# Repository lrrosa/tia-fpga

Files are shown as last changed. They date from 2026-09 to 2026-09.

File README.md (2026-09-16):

# tia-fpga

An FPGA replacement for the **Television Interface Adaptor (TIA)** — the custom
`C010444` / `C010444D` (NTSC) video and sound chip of the Atari 2600.

Revision **B** is the digital interface board between a Sipeed Tang Nano 9K
module and the TIA's DIP-40 socket, for use with a real 6507 (on a breadboard or
in an actual 2600). Revision A, the first study, was never built.

| Front | Back |
|:---:|:---:|
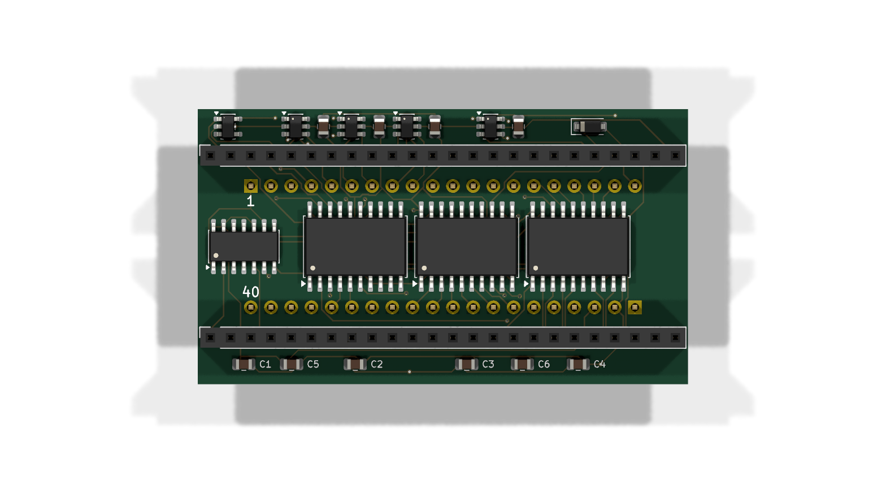
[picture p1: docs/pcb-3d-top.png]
Front of the board
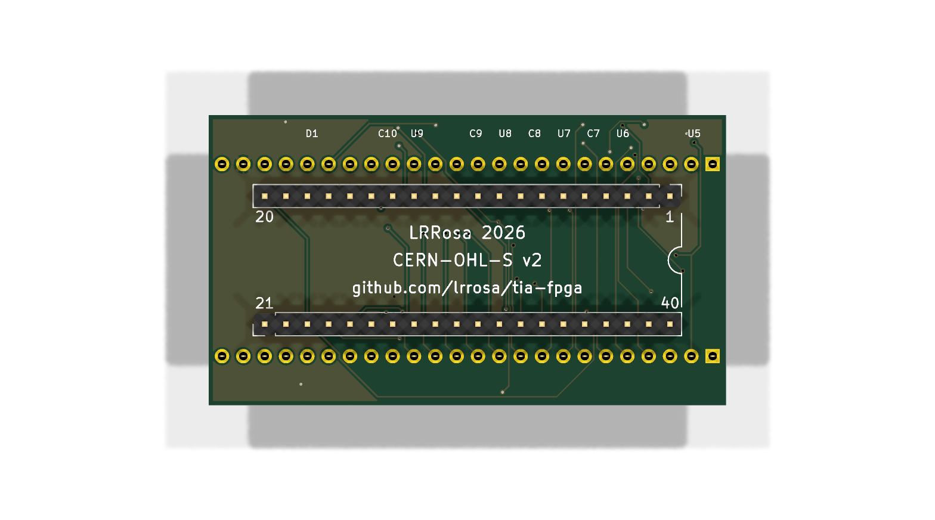
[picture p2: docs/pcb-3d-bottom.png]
Back of the board
|  |  |
| Tang Nano sockets face **up**; the logic sits in the channel between the rows | The TIA's DIP-40 pins face **down** into the socket, over the ground pour |

61.6 × 34.54 mm, two layers. Every row lands on the 2.54 mm grid — the
DIP-40's 15.24 mm and the Tang Nano's 22.86 mm — and the board is a little
shorter than the module it carries, as it has to be: in a real 2600 the TIA,
the 6507 and the RIOT sit millimetres apart.

---

## Why this exists

The TIA has **6,193 transistors** — 1,657 of which are NMOS pull-ups, leaving
about 4,500 of actual logic. It fits in any modern FPGA with room to spare:
synthesising a known implementation yields **311 flip-flops** and roughly 2,200
basic gates.

Size was never the problem. Two other things are:

1. **The analogue boundary.** The chroma generator is an analogue delay line
   trimmed by an external 500 kΩ potentiometer (pin 10, `DEL`). It has no direct
   digital equivalent.
2. **5 volts.** No FPGA with enough capacity is 5 V tolerant. And the TIA
   generates the 6507's Φ0 clock, which requires
   V<sub>IH</sub> = V<sub>cc</sub> − 0.2 V ≈ **4.8 V** — not a TTL level. A 3.3 V
   output will not clock the 6507 reliably, and the failure mode is nasty: it
   works intermittently, or works cold and quits once warm.

This revision solves (2) and leaves (1) for later.

## What is on the board

| Ref | Part | Function |
|-----|---|---|
| J1, J4 | 1x24 sockets | Sipeed Tang Nano 9K module (GW1NR-LV9QN88PC6/I5): J1 takes its **J6** row, J4 its **J5** |
| J2, J3 | 1x20 SIP strips | Plug into the DIP-40 socket in place of the C010444 |
| D1 | MBR0540 | Feeds the module's 5 V pin from the socket, and blocks its USB from feeding the console |
| **U1** | **74AHCT125** | **Φ0 and RDY buffer, powered from +5 V.** The critical part |
| U2 | 74LVC245A | D0–D7 bidirectional bus. A side = FPGA, B side = TIA |
| U3 | 74LVC541A | A0–A5 and R/W into the FPGA; Φ2 buffered to a spare pad |
| U4 | 74LVC541A | /CS0, /CS3, triggers I4/I5 and the 3.579545 MHz crystal clock |
| U5 | 74LVC1G32 | `/CS0 OR /CS3`: `/OE` for the 245, and the FPGA's chip select |
| U6–U9 | 74LVC2G07 | Open-drain drivers for SYNC, LUM0–2, COL, BLK, AUD0 and AUD1 |

The video and sound pads — SYNC, LUM0–2, COL, BLK, AUD0 and AUD1 — each go
through one channel of U6–U9. On the die every one of them is a pull-down
transistor and nothing more; the buffers make the board's pins the same, open
drain and 5 V tolerant, so the console's own pull-ups set every level. See
*Pads and levels* below.

Pin 10 (`DEL`) is marked no-connect: it is the colour trim pot, which has no
function in a replacement.

Neither of the 245's control lines comes from the FPGA. The A side faces the
FPGA, so `DIR` can be driven straight from the buffered R/W (`DIR`=1, a read,
sends FPGA → TIA), and `/OE` comes from U5. That is deliberate — see the pin
budget below.

## The pin budget, and why it constrains everything

The Tang Nano 9K's headers are 2×24, but **only 29 of those 48 pins are usable
3.3 V GPIO**:

| | Count | |
|---|---|---|
| J5 pins 1–22 | 22 | banks 1/2 at 3.3 V — all usable |
| J6 pins 1, 10, 11, 19–22 | 7 | 3.3 V — usable |
| J6 pins 2–9 | 8 | **BANK3 at 1.8 V — not usable at 3.3 V** |
| J5 23–24, J6 12–17 | 8 | HDMI differential pairs — not GPIO |
| J6 18, 23, 24 | 3 | +5V (fed through D1), GND, +3V3 |

Verified against both revisions of the official Sipeed board schematic (3672 and
3674), which agree exactly. Many of the 29 are shared with onboard peripherals
(SD card, RGB LCD, SPI LCD); they are free to reuse as long as you do not fit
those.

**Rev B uses all 29 with nothing spare.** A fully featured TIA needs about 36.
`BLK` has its pin because the FPGA reads `/CS0 OR /CS3` from U5, which makes it
for the 245 anyway, instead of taking the two selects separately.

**Chroma is fitted.** `F_COL` took the pin that used to carry Φ2, and that trade
is deliberate rather than grudging: the FPGA generates Φ0 itself, so it knows
where it is in the bus cycle and can time accesses off its own clock instead of
the 6507's output. It costs a little timing fidelity and buys back colour on the
composite and RF path — which is the difference between a board that only works
with an HDMI monitor and one that revives a console with a dead TIA while
keeping its original video. Φ2 is still buffered by U3, brought out to an
unconnected pad for a future revision.

What still does not fit: the four paddle inputs plus their dump/compare control.

Two ways to get the remaining pins back:

1. **Recover J6/2–9** (8 pins) with a local 1.8 V LDO and a fourth buffer powered
   at 1.8 V. LVC parts run down to 1.65 V and their inputs stay 5 V tolerant, so
   this works — it just adds a rail. This is the cheapest way to the paddles.
2. **Drop the module and put a bare FPGA on the board.** A part in a TQFP-100
   gives ~78 I/O against the module's 29, which ends the pin shortage outright,
   removes U5, brings Φ2 back and makes the paddles possible — and collapses a
   ~20 mm tall stack into a 1 mm chip, which matters if this has to live inside
   a closed console. It costs fine-pitch soldering and your own configuration
   and power plumbing. See `docs/bare-fpga.md`.

This is the single most important thing to know before ordering parts: the Tang
Nano 9K is big enough in *logic* by a wide margin, and tight in *pins*. Every
compromise in this design traces back to that.

## The board

Rev B is a 2-layer, **61.6 × 34.54 mm** board — shorter than the Tang Nano it
carries. In a real 2600 the TIA, the 6507 and the RIOT sit millimetres apart,
ringed by resistor networks and the cartridge slot, so the board cannot spread
sideways. The two sets of rows face opposite ways:

| y (mm) | Row | Side | Faces |
|---|---|---|---|
| 5.84 | J1 — Tang Nano **J6** | F.Cu | socket, **up** |
| 9.65 | J2 — TIA pins 1–20 | **B.Cu** | pins, **down** into the socket |
| 24.89 | J3 — TIA pins 21–40 | **B.Cu** | pins, **down** |
| 28.70 | J4 — Tang Nano **J5** | F.Cu | socket, **up** |

Both pitches land on the 2.54 mm grid: the DIP-40 rows 15.24 mm apart, the Tang
Nano's 22.86 mm, and the DIP pair centred between the sockets — 3.81 mm of gap
on each side. Which socket takes which module row is not free — see
[Which row is which](#which-row-is-which). SMD logic sits on the front in the
15.24 mm channel between the DIP rows. The open-drain drivers and their
capacitors sit in the top margin, right above the TIA pins they drive, with D1
beside them, and the channel's decoupling in the bottom margin.

| | |
|---|---|
| Size | 61.6 × 34.54 mm, 2 layers |
| Components | 24 — SOIC/SOT-23 logic, 0805 capacitors, one diode, through-hole connectors |
| Routing | 534 segments, 39 vias, 1.48 m of copper |
| Ground | B.Cu pour, 759 mm² in two islands, tied together by track |
| Track / clearance | 0.18 mm / 0.13 mm |
| **DRC** | **0 violations, 0 unconnected pads** |

### Pin assignment is solved, not listed

Which signal sits on which header position is free — any GPIO can carry any
signal — so it is chosen to put each FPGA pin as close as it can be to the pad
its net really reaches: the buffer or gate between it and the TIA socket, not
the socket pin beyond it. Solved as an assignment problem (Hungarian, over the
29 usable positions, Manhattan distance to those pads), the whole set comes to
571 mm. `F_OSC` is held to J6/1, the right PLL's own input, which costs 25.6 mm
of that and keeps the colour clock off the FPGA's general routing.

The sum is what the module's own geometry allows: J5 carries 22 of the 29
signals and sits on the row *away* from the TIA's pins 1–20, so most of the bus
crosses the channel whatever the assignment does. Solving it still beats the
alternative — the same signals laid out by hand come to 685 mm.

Rev A measured the distance to the TIA pin itself, which left out the detour
through the buffers: its data and chip-select lines crossed the board twice.
The buffers stay ordered left to right by the centroid of what they carry,
**U1, U4, U3, U2**, and against rev A the board saves copper while gaining five
parts:

| | rev A | rev B |
|---|---|---|
| Segments | 601 | **534** |
| Vias | 31 | **39** |
| Copper | 1.68 m | **1.48 m** |

`fpga/tia_fpga.cst` carries the result. Do not reshuffle those `IO_LOC` lines
casually — the layout depends on them.

Autorouted with [Freerouting](https://github.com/freerouting/freerouting) 2.2.4:
all 120 nets in about 12 s but three ground connections. Two are closed with a
via dropped on the branch's own track where it passes over the pour, and the
last two capacitors are tied to their neighbours along the free lane that runs
just inside the top edge. The channel leaves only ~1.1 mm between the header pads and the SOIC
pads, so the geometry decides whether it routes at all: it takes 0.13 mm
clearance and 0.18 mm track. The ground pour is added **after** routing —
Freerouting reads a pour as an obstacle and goes effectively single-layer if one
is present.

Files: `tia-fpga.kicad_pcb`, renders in `docs/`, fabrication output in `gerbers/`.

### Ordering a board

The files in `gerbers/` are ready for any PCB house as they are — Gerber X2
plus Excellon drill, with `FABRICATION-NOTES.txt` alongside them; zip them with
the files at the root of the archive. Nothing in it needs more than standard
low-cost capability:

| | |
|---|---|
| Size / layers | 61.6 × 34.54 mm, 2 layers, 1.6 mm FR4 |
| Min track / clearance | 0.18 mm / 0.13 mm |
| Drills | 0.30 mm (vias), 1.00 mm (connectors) |

`docs/bom-production.csv` is the parts list with suggested orderable numbers.
Three assembly points that are easy to get wrong:

- **J2/J3 mount on the BACK, pins facing DOWN**, and want **round machined
  pins** — square header pins damage a DIP socket.
- **U5–U9, C7–C10 and D1 carry their designators on the back silkscreen**,
  right behind each part: the top margin has no room for them on the front.
- **The module goes in component side up, USB-C end to the left** — see below.
- **The back silkscreen carries the licence notice** — `CERN-OHL-S v2`,
  `LRRosa 2026` and `github.com/lrrosa/tia-fpga`, between the two rows of TIA
  pins. The licence asks for it to travel with the board; keep it on a respin.
- **Pin 1 of the TIA is at the half-moon end.** The back carries that half moon,
  keyed like the chip's own package, and the numbers 1, 20, 21 and 40 beside the
  corner pads; the front repeats 1 and 40.

### Which row is which

The Tang Nano's two rows are **22.86 mm** apart (9 × 2.54), from Sipeed's own
dimension drawing, `Tang_Nano_9K_3672_size`. Pin 1 of both rows is at the USB-C
end, 2.55 mm from that edge; the HDMI connector is at the other end and
overhangs this board by about 7.5 mm, with a millimetre of module sticking out
at the USB end as well. Both hang in free air, 20 mm above the console.

Looking down at the module with the USB-C end on the left, **J6 is the upper
row and J5 the lower one**, so J1 takes J6 and J4 takes J5. Three things say so
and agree: the pin numbers silkscreened on the module's underside, the QN88's
own pin order on the top-side photo in Sipeed's datasheet, and third-party
carrier boards for the module. On your own board, look for **63** beside pin 1
of one row and **38** beside pin 1 of the other: 63 is J6/1, which this board
wires to `F_OSC`.

Rev A and the first cut of rev B had both of these wrong — 20.32 mm, and the
rows the other way round. Nothing was ever fabricated from them.

The DIP-40 row spacing (15.24 mm) is fixed by the package and is not a guess.

**The board needs tall pins.** It overhangs the neighbouring 6507 and RIOT, which
sit proud of the 2600's PCB in their own sockets. Standard DIP header pins would
put this board straight into them; a socket extender or long machined pins are
required. Measure the vertical clearance in your console — the Tang Nano's HDMI
connector adds roughly 5 mm on top.

**There are no mounting holes.** The board is held by its own pins in the TIA
socket, and there is nothing to screw into inside a 2600. Adding holes only
forced the board larger, so they were dropped.

### Known limitations

- The four paddle inputs still do not fit — see the pin budget above.
- No ground pour on F.Cu; only B.Cu is poured.

### Pads and levels

Reading the die's netlist for the RTL settled something the schematic had
assumed. **Every video and sound pad on the TIA — SYNC, LUM0–2, COL, AUD0,
AUD1, and BLK and RDY too — is a pull-down transistor and nothing else.** None
of them can drive high. Φ0 is the only output with a real driver on both
sides.

The console schematics show the other half:

| | 2600A, rev 16 | 2600 (the original board) |
|---|---|---|
| LUM0–2, SYNC | R218–R221, 3.3–4.7 kΩ to +5 V, straight into the summing resistors (R214–R217: 27, 47, 110, 24 kΩ) | R218–R221, 3.3 kΩ to +5 V, into a CD4050 run from a divider off +5 V (R231, R232: about 3.6 V), then the summing resistors (R222–R224, R234: 12, 24, 47, 10 kΩ) |
| COL | R228, 1 kΩ to +5 V; C210, 47 pF, to a second 1 kΩ pull-up (R211); 6.8 kΩ and 22 pF into the sum | R212, 1 kΩ to +5 V; C212, 47 pF, to a second 1 kΩ pull-up (R214); 22 pF and 6.8 kΩ into the sum |
| BLK | R234, 820 Ω, into the COL node (revs 14 and 15: not connected) | R213, 680 Ω, into the COL node |
| AUD0, AUD1 | joined; R206, 1 kΩ to +5 V; 0.1 µF and 18 kΩ into the sound oscillator | joined; R208, 1 kΩ to +5 V; the same coupling |

PAL consoles use a different TIA (C011903): one sound pad, AUD on pin 13 with
its own 1 kΩ pull-up, while pins 12 and 8 carry the PAL signals. This board is
for the NTSC chip.

Rev B follows the die:

- **Open drain, 5 V tolerant.** Each of those pads goes through one channel of
  a 74LVC2G07 (U6–U9) powered at 3.3 V. The FPGA drives the channel's input:
  0 pulls the socket pin low, 1 lets it go, and the console's pull-up takes the
  line wherever it took the TIA's — 5 V on a 2600A's luma lines, the CD4050's
  input on an original 2600, the colour and sound nodes through their 1 kΩ.
  Nothing on the socket side reaches the FPGA's pins.
- **BLK is driven.** It pulls low through the whole blanking interval. On the
  original 2600 (through 680 Ω) and the 2600A from rev 16 (820 Ω) it drags the
  colour node down with it: against the 1 kΩ pull-up that node only reaches
  about 2 V while blanking, so the burst — the only colour sent then — gets
  well under half the swing of the picture's colour, and a TV sets its colour
  gain by the burst. On revs 14 and 15 of the 2600A the pin is not connected,
  and nothing changes.
- **The two sound pins are joined** by a trace on an unmodified 2600, which
  open drain makes harmless either way. By default `tia_board.v` still puts
  the same pulse-width mix of both channels on both pins; for a console
  modified for stereo, `AUDIO_STEREO = 1` gives each pin its own channel, in
  non-overlapping halves of the pulse frame so the two still add correctly
  wherever they meet.
- **No video network on the board.** Rev A carried a copy of the console's
  resistor network, for use outside a console. With open-drain pads it would
  have needed all of it — pull-ups, summing resistors, the colour coupling and
  BLK's resistor — so rev B leaves it off. To take video from the socket pins
  on a breadboard, build the 2600A rev 16 column of the table above.

## Two ways to use this

**Reviving a dead console.** Pull the failed TIA, drop this in its socket, and
keep the 2600's own RF modulator or composite mod. Chroma, luma, sync and audio
come out on the same socket pins the original chip used, open drain as the
chip's are, so the console's video path is untouched.

**As a development target.** Plug it into a breadboard next to a real 6507.
The Tang Nano's HDMI connector would cost no header pins — its pins are
dedicated differential pairs on the module — but the RTL has no TMDS encoder
yet, so for now the picture comes from the socket pins, through a network like
the console's.

## The RTL

`rtl/` holds the core: horizontal counter, playfield, two players, two
missiles, ball, collisions, HMOVE, audio and the bus interface, in eleven files
of plain Verilog-2005, plus `tia_board.v`, which puts it on this board. `sim/`
holds the test harness the section below argues for, and it is not
aspirational: the core is checked against
[Sim2600](https://github.com/gregjames/Sim2600) half clock by half clock, on a
real game and on test cartridges written to hit each feature from every phase
that matters.

```bash
python sim/run.py
```

Against Donkey Kong from power-on to its first picture, and against every test
cartridge -- playfield, players, missiles, ball, collisions, HMOVE with Cosmic
Ark, resets at every phase of HBLANK, vertical delay and both sound cartridges
-- the core matches the die on every pin at every half clock.
[`sim/README.md`](sim/README.md) has the table. (The Donkey Kong traces are regenerated locally rather
than committed, since they carry the game's artwork.)

**Sim2600 wires one clock wrong, and both wirings are now in the suite.**
Upstream Sim2600 feeds the TIA's Φ2 input from the 6507's Φ1 output, the
inverse of what the console does. The die only looks at that pin through
write strobes, so everything still worked, but every write landed on the other
half of the colour clock from where a real console puts it. With the console's
wiring (`sim/patches/sim2600-phi2.patch`, traces in `sim/traces/phi2/`), five
of the core's timing rules turned out to have been fitted to the wrong side
and were re-read from the netlist — RSYNC's restart, RDY's release, how
long a reset holds an object's clock, the size gate of stretched players and
when HMOVE's comparators see a new value. The last mismatch was a mechanism
no rule had covered: HMOVE pulses in the visible line merge into the object
clocks and show on the pads half a colour clock early. The core now matches
both sets on every pin of every trace.

**The board.** `rtl/tia_board.v` is everything between the core and the board's
pins: the core's clock from a PLL locked to the console's crystal, Φ2 rebuilt
from the Φ0 the board makes itself, the data bus, chroma as that clock shifted
in phase by hue, and sound as pulse width. `fpga/tia_fpga_top.v` adds the Gowin
PLL, bus buffers and chroma ODDR. `sim/tb_board.v` replays the console-wired
traces into the board logic and checks every pin it drives, and
`fpga/build_gowin.tcl` builds the bitstream with Gowin EDA — from a directory
whose path has no spaces, since Gowin's place and route will not run in one
that does.

Getting there turned up a good deal the published documentation does not say,
all of it now in the source: which edge of the colour clock each latch runs on;
that Φ0 is a 50 per cent square wave reloaded by the horizontal counter; what
RSYNC actually does, which Towers left as "requires more investigation"; that
HMOVE's first compare must come before its first decrement, or an HMxx of -8
moves an object sixteen pixels the wrong way; that HMOVE's pulses past HBLANK
merge into the object clocks instead of counting; and exactly when a mid-line playfield
write reaches the screen. Once the harness could record the die's internal
wires as well as its pins, the netlist itself settled the rest: how a RESxx
strobe really resets an object -- by holding its clock, not by zeroing its
counter -- and how the sound counters are clocked, down to the discovery that
the two audio channels are not wired alike.

**Clocking.** The real chip is clocked by the 3.58 MHz colour clock and uses
both its edges. This core takes a faster system clock and treats the colour
clock as a signal to oversample, so everything is one clock domain, one edge,
no gated clocks. On this board `clk0` comes from the console's own crystal
through U4 and the system clock from a PLL, so the core stays locked to the
machine it is plugged into.

## Status

- [x] Rev B schematic — passes KiCad 10 ERC with 0 violations
- [x] FPGA pin assignment (`fpga/tia_fpga.cst`)
- [x] PCB layout — rev B routed, ground pour, DRC clean (0 violations, 0
      unconnected pads)
- [x] Open-drain video and sound pads and `BLK` on pin 6 — U6–U9, with
      `sim/tb_board.v` checking `BLK` against the die
- [x] Sim2600 test harness — traces, replay testbench, test cartridges
- [x] TIA RTL — matches the die on a real game and on every test cartridge
- [x] Audio -- read off the die's netlist; both channels match on every trace
- [x] Object resets, scan clock, widths and HMOVE timing -- read off the netlist
- [x] Board wrapper — `rtl/tia_board.v` and `fpga/tia_fpga_top.v`: PLL off the
      console's crystal, Φ2 rebuilt from Φ0, data bus tri-state, chroma through
      an ODDR, sound as pulse width. Checked pin by pin against the traces by
      `sim/tb_board.v`
- [x] Traces with the console's wiring of Φ2 — Sim2600 feeds the TIA the
      6507's Φ1; `sim/patches/sim2600-phi2.patch` fixes that and
      `sim/traces/phi2/` holds the re-recorded set
- [x] Synthesis check: Yosys `synth_gowin` with no warnings — the core is
      514 flip-flops and 740 LUTs, the whole board top 622 and 705, under
      10 per cent of the GW1NR-9 (`fpga/check_synth.py`)
- [x] Gowin EDA build (V1.9.11.03 Education): bitstream, no setup or hold
      violations at the slow corner, 60.4 MHz Fmax against the 57.27 MHz
      clock (`fpga/build_gowin.tcl`)
- [x] Stretched players reset mid-copy, Cosmic Ark and HMOVE pulses in the
      visible line, with the console's wiring — every trace matches
- [ ] Paddle circuit (still needs pins, see above)
- [x] Composite video path wired — the chroma pin is fitted and `tia_board.v`
      synthesises the 15 subcarrier phases, as the colour clock shifted in
      phase by hue through an ODDR (`HUE_TURN`). Never yet seen on a television
- [x] Tang Nano interface checked against Sipeed's own dimension drawing: rows
      22.86 mm apart, J6 on J1, and the module fed from the socket through D1
- [x] Boot time — the bitstream loads at 31.25 MHz (`-loading_rate 250/8` in
      `fpga/build_gowin.tcl`), about 8 ms, against the 17–58 ms the console
      takes to release the 6507's reset. Still to be measured on hardware

## Opening the project

Requires **KiCad 10**. Only stock libraries are used — there are no custom
symbols or footprints to install.

```bash
kicad tia-fpga.kicad_pro
```

To run ERC from the command line:

```bash
kicad-cli sch erc tia-fpga.kicad_sch -o erc.rpt --severity-error --severity-warning
```

## Suggested order of work

1. ~~**Build the test harness first.**~~ Done -- `sim/`. Comparing half clock
   by half clock against [Sim2600](https://github.com/gregjames/Sim2600) -- not
   an emulator, but the netlist extracted from the die shot, simulated
   transistor by transistor -- earned its keep at once. Most of what it caught
   were things the documentation states plainly enough that they looked
   settled, and none of them would have been findable by looking at a picture.
2. ~~**Rewrite the TIA one block at a time**~~ -- done, in dependency order:
   horizontal sync counter, playfield, players, missiles and ball, collisions,
   HMOVE. HMOVE really is the most treacherous; leave it last.
3. ~~**Widen the coverage.**~~ Done: the test cartridges in `sim/roms/` cover
   every CTRLPF, NUSIZ, HMOVE and AUDC value, and resets at every phase of
   HBLANK, and the core matches the die on all of them.
4. ~~**Board wrapper and synthesis**~~ -- done: `rtl/tia_board.v`,
   `fpga/tia_fpga_top.v`, `fpga/tia_fpga.sdc`, `fpga/build_gowin.tcl`.
5. **Run it on the Tang Nano alone** before touching real hardware, to separate
   bugs in the TIA from bugs in your bench wiring. Nothing here does that yet:
   the module would need the rest of the console beside the core -- a 6502, the
   RIOT and a cartridge image -- or a player that replays the recorded bus
   writes in `sim/traces/`, and either way a TMDS encoder and line doubling to
   put the picture on HDMI.
6. **This board** -- TIA-only, with a real 6507.
7. Paddles.
8. Composite colour: the phases are generated; what is left is a television to
   check the hues and the burst level against.

## Timing quirks that matter

Almost every one of these is a bug in the original chip that games came to rely
on. They are what separates "runs Combat" from "runs Pitfall II":

- **Almost none of the TIA's counters are binary.** They are polynomial
  counters (LFSRs) with wired-AND decode matrices — the horizontal sync
  counter, all five object position counters, and the audio generators. Binary
  counters with comparators will run games but get the edge effects wrong. The
  exception is each sound channel's frequency divider: a binary counter
  *compared* with AUDF, not loaded from it, so lowering AUDF below the count
  makes it run on to 31 before the channel ticks again.
- **HMOVE comb.** Strobing `HMOVE` delays the end of HBlank (the LRHB line),
  producing the 8-pixel black bar at the left edge. Pitfall II depends on it.
- **Cosmic Ark starfield.** Writing HMxx during the HMOVE window makes the
  comparator see a still-running counter. The resulting pattern *differs between
  TIA revisions*.
- **RESPn latency.** A reset strobe does not zero the counter. It holds the
  object's two-phase clock in H@1 and sets a latch, and the counter clears on
  the next H@2. A copy that was already decoded therefore survives the reset,
  and inside HBlank, where the object clock is stopped, the clear waits for
  the first colour clocks of the visible line.
- There are at least **12 NTSC TIA revisions** with observable differences.
  Decide which one you are cloning before you start.

## References

- [TIA Hardware Notes](https://www.atarihq.com/danb/files/TIA_HW_Notes.txt) — Andrew Towers, 2003. Polynomial counters, HCount tables, HMOVE timing. Does not cover audio or colour generation.
- [TIA internal schematics](https://www.atariage.com/2600/archives/schematics_tia/index.html) — 5 sheets scanned by Mark De Smet. Sheet 1: sync counter, playfield and motion registers. Sheet 2: collision register. Sheet 3: object/missile motion counters. Sheet 4: audio circuits. Sheet 5: ball motion counter.
- [10444D die shots](http://www.visual6502.org/images/pages/Atari_10444D_TIA.html) — visual6502
- [TIA Technical Manual](https://archive.org/stream/Atari_2600_TIA_Technical_Manual/Atari_2600_TIA_Technical_Manual_djvu.txt)
- [Atari 2600 Specs](https://problemkaputt.de/2k6specs.htm) — Nocash; the cleanest register map there is
- [Tang Nano 9K documentation](https://dl.sipeed.com/shareURL/TANG/Nano%209K/) — Sipeed

---

## Licence

Copyright 2026 Leonardo Roman da Rosa

```
SPDX-License-Identifier: CERN-OHL-S-2.0
```

This source describes Open Hardware and is licensed under the CERN-OHL-S v2.

You may redistribute and modify this source and make products using it under
the terms of the CERN-OHL-S v2 (https://ohwr.org/cern_ohl_s_v2.txt).

This source is distributed WITHOUT ANY EXPRESS OR IMPLIED WARRANTY, INCLUDING OF
MERCHANTABILITY, SATISFACTORY QUALITY AND FITNESS FOR A PARTICULAR PURPOSE.
Please see the CERN-OHL-S v2 for applicable conditions.

Source location: https://github.com/lrrosa/tia-fpga

As per CERN-OHL-S v2 section 4, should You produce hardware based on this source,
You must where practicable maintain the Source Location visible on the external
case of the Gizmo or other products you make using this source.

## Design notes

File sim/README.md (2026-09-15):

# Testing the RTL against Sim2600

This is the oracle the project README argues for. [Sim2600](https://github.com/gregjames/Sim2600)
is not an emulator — it is the 6507 and TIA netlists pulled off die photographs
by the visual6502 project, simulated transistor by transistor. It is the
closest thing to a reference TIA that exists short of putting a logic analyser
on a real console, and it is the only way to tell "my HMOVE is wrong" apart
from "that is how the chip actually behaves".

The idea is deliberately narrow:

1. Run a cartridge on Sim2600 and write down, every TIA half clock, **what was
   on the chip's pins** — both what the console drove in and what the die drove
   back.
2. Replay the recorded **inputs** into the RTL and check the recorded
   **outputs**.

Nothing in the loop depends on anyone's idea of what the 6507 should have been
doing. A mismatch always means the RTL does not behave like the silicon.

---

## Quick start

```bash
python sim/run.py
```

That builds the core with Icarus Verilog and replays every trace in
`sim/traces/` and `sim/traces/local/`, then the same cartridges recorded with
the console's wiring of the TIA's Φ2 pin, in `sim/traces/phi2/` and
`sim/traces/local/phi2/` (see *Which clock the TIA sees*). It takes a few
minutes; `--align 0` skips the alignment search and makes it quicker.

The `local` directories are different on purpose. `sim/traces/` holds traces
of the project's own test cartridges and is committed. `sim/traces/local/`
holds traces recorded from commercial cartridges and is ignored by git: even
with the bus scrubbed (see *Trace format*), what a game writes into GRP0 and
PF0-PF2 is its artwork, and that is not ours to publish. Regenerate those
locally with the commands under *Generating a trace*.

## Current results

Every trace is recorded twice from the same cartridge: once with Sim2600 as it
comes, and once with CLK2 wired the way the console wires it. "Match" means
every pin at every half clock scored — Φ0, RDY, composite sync, blanking,
luminance, colour, the data bus drivers and both audio pads.

| trace | what it exercises | half clocks scored | Sim2600's wiring | console's wiring |
|---|---|---:|:---:|:---:|
| `local/donkeykong-boot-to-picture` | a real game, power-on to its first picture | 51,657 | match | match |
| `local/donkeykong-power-on` | the first 6,000 half clocks, both RSYNCs | 3,657 | match | — |
| `playfield` | every CTRLPF mode, mid-line PF writes | 54,063 | match | match |
| `players` | every NUSIZ mode at all four sub-count phases | 46,767 | match | match |
| `missiles` | widths, copies, RESMP at every player size | 55,887 | match | match |
| `ball` | widths at every phase, RESBL retriggering, VDELBL | 44,031 | match | match |
| `collisions` | everything overlapping, all eight CX reads, input ports | 34,911 | match | match |
| `hmove` | all sixteen values, HMOVE late and mid-line, Cosmic Ark | 28,983 | match | match |
| `resets_hblank` | RESP0 at three sizes, RESM0 and RESBL, at every phase of HBLANK | 85,071 | match | match |
| `vdel` | VDELP0 and VDELP1 in all four combinations | 17,583 | match | match |
| `audio` | the volume DAC, and every AUDC mode on both channels | 90,543 | match | match |
| `audio_modes` | each AUDC mode for 80 ticks, the 9-bit polynomial for a whole period, the divider | 457,167 | match | match |

The suite reports FAIL on a single mismatched half clock, with no tolerance
anywhere, so a regression on any pin of any trace shows at once.

## What you need

| | |
|---|---|
| **Icarus Verilog** 11 or later | `winget install Icarus.Verilog`, `apt install iverilog`, `brew install icarus-verilog` |
| **Python 3.8+** | to generate traces and to drive the build |
| **Sim2600** | only to generate traces |

`run.py` looks for `iverilog` and `vvp` on PATH and then in `C:\iverilog\bin`,
which is where the Windows installer puts them and where it does not add them
to PATH.

## Setting up Sim2600

```bash
git clone -c core.autocrlf=false https://github.com/gregjames/Sim2600.git
cd Sim2600
git checkout af3bc453e253172503967ffb826377517b95a62a
git apply ../tia-fpga/sim/patches/sim2600-py3.patch
```

For the console's wiring, make a second checkout the same way and apply one
more patch on top:

```bash
git clone -c core.autocrlf=false https://github.com/gregjames/Sim2600.git Sim2600-phi2
cd Sim2600-phi2
git checkout af3bc453e253172503967ffb826377517b95a62a
git apply ../tia-fpga/sim/patches/sim2600-py3.patch
git apply ../tia-fpga/sim/patches/sim2600-phi2.patch
```

**`core.autocrlf=false` is not optional on Windows.** `chips/net_TIA.pkl` is a
protocol-0 pickle, which is mostly ASCII, so git's autocrlf heuristic decides
it is a text file and rewrites every `\n` in it as `\r\n`. The file still looks
fine and is still about the right size; it just fails to unpickle, with
`UnpicklingError: the STRING opcode argument must be quoted`. If you already
cloned it the wrong way, delete the checkout and clone again — `git checkout`
alone will not undo it. Put the `-c` after `clone`, as above: that writes the
setting into the new repository's own config, so the `checkout` and `apply`
that follow keep it too.

`sim2600-py3.patch` ports Sim2600 to Python 3. It is small and mechanical:
`print` statements, `xrange`, integer division, `RuntimeException`, iterating
over bytes, and `pickle.load(..., encoding='latin1')` for the Python 2 netlist
files. It also fixes one upstream typo — `writeMemory` sets `pia.timerVal`
where every reader says `pia.timerValue`, so the PIA timer never actually
loaded its initial value. That does not change the shape of the comparison (the
trace is replayed either way) but it makes the oracle a more faithful 2600.

`sim2600-phi2.patch` is the clock wiring, explained in the next section.

Sim2600 is MIT licensed, and the patches are modifications of it, so they are
offered under the MIT licence too, not the CERN-OHL-S that covers the rest of
this repository. Their headers say so.

## Which clock the TIA sees

Upstream `sim2600Console.py` drives the TIA's CLK2 pad from the 6507's
**CLK1OUT**. On the console, TIA pin 26 is wired to the 6507's Φ2 output — in
the visual6502 netlist, **CLK2OUT**, the other polarity. The traces say so too:
in an upstream trace `clk2` is the inverse of `ph0` one half clock later, and
the 6507 puts a new address on the bus as that pad rises, its write data as it
falls. On a 6502 the address comes out in phase 1 and the data in phase 2, so
the pad the die was given is high in phase 1.

The die only looks at that pin through its bus strobes, so the simulation ran
happily either way. What changes is where every write lands against the colour
clock: each write strobe on the die is high for the three half clocks CLK2 is
low after the write, and with the wiring flipped those three half clocks sit
on the other side of PH0 and start on the other edge of the colour clock. Any
rule this core had fitted from one wiring alone could have been fitted to the
wrong side, and several were: RSYNC's restart, RDY's release, how long a
reset holds an object's clock, the size gate of stretched players, and when
HMOVE's comparators see a new HMxx value (all below, as read off the
netlist).

`sim2600-phi2.patch` takes CLK2 from CLK2OUT, and updates it at the start of
each half clock, before the bus, because on the console Φ2 falls before the
6507 moves its address. `sim/traces/phi2/` was recorded with it.

Two things in the harness follow from that order. A trace record shows the bus
*after* the 6507 moved it, so with the console's wiring the record in which
CLK2 falls already shows the next cycle, while the die latched the old one.
`tb_trace.v` therefore tells the two wirings apart by how `clk2` follows `ph0`
and, for the console's, holds the bus while CLK2 is low, which is what the
die's own latch does. And the board has no Φ2 pin at all — it rebuilds Φ2 from
the Φ0 it makes — so `tb_board.v` checks the rebuilt one against these traces.

## Test cartridges

`sim/roms/` builds the cartridges behind the committed traces:

- `tinyasm.py` — a 6502 assembler small enough to read in one sitting, so the
  harness needs nothing beyond Python and Icarus. Every instruction is a
  method named after its mnemonic and addressing mode: `a.sta_zp(WSYNC)`,
  `a.bne("loop")`.
- `tests.py` — one function per cartridge. None of them bothers with VSYNC or a
  proper frame: the harness compares pins, not pictures, so every scanline can
  be a test line.
- `make.py` — builds the cartridges and records their traces, several
  Sim2600 runs at a time.

```bash
python sim/roms/make.py --list
python sim/roms/make.py --sim2600 ../Sim2600                 # every test
python sim/roms/make.py --sim2600 ../Sim2600 players hmove   # just these
python sim/roms/make.py --sim2600 ../Sim2600-phi2 --traces sim/traces/phi2
```

Every cartridge starts by clearing zero page, which writes every TIA register —
RSYNC included. That is on purpose: RSYNC restarts the die's horizontal counter
from the bus, so nothing after it depends on whatever phase the die powered up
in.

The tests do not try to predict where a strobe lands; the die's answer is in
the trace. They step a delay loop so strobes land on every phase that matters:
a five-cycle step is 15 colour clocks, which is 3 mod 4, so four consecutive
steps visit all four phases of an object counter.

They exist because a game only covers what it happens to do. Donkey Kong's
title screen uses players and very little else, and it passed cleanly while the
playfield was still a colour clock late and an HMOVE of −8 moved objects
sixteen pixels the wrong way.

## Generating a trace from a game

```bash
python sim/gen_trace.py --sim2600 ../Sim2600 --rom DonkeyKong.bin --quiet \
       --skip 0 --count 54000 \
       --out sim/traces/local/donkeykong-boot-to-picture.trace
python sim/gen_trace.py --sim2600 ../Sim2600 --rom DonkeyKong.bin --quiet \
       --skip 0 --count 6000 \
       --out sim/traces/local/donkeykong-power-on.trace
python sim/gen_trace.py --sim2600 ../Sim2600-phi2 --rom DonkeyKong.bin --quiet \
       --skip 0 --count 54000 \
       --out sim/traces/local/phi2/donkeykong-boot-to-picture.trace
```

Sim2600 settles roughly ten thousand transistors per half clock, so it runs at
about **3 ms per half clock** — half a second per scanline, two and a half
minutes per frame. Plan around that:

- `--count N` records N half clocks. 456 of them is one scanline, so 54,000 is
  about 118 lines — enough for Donkey Kong to get from power-on to its first
  visible pixels, which is what it takes.
- `--skip N` runs N half clocks without recording. Useful for looking at
  something specific, but see the warning below before you reach for it.
- `--wait-visible MAX` runs on after `--skip` until the picture unblanks.

**Start traces at power-on: use `--skip 0`.** A trace that begins in the middle
of a game is not a fair test, because the die's register file holds whatever
the cartridge wrote before the recording started, while the core comes out of
reset with everything at zero. Nothing in the trace can tell it what COLUP0
was.

A trace with no visible picture in it still checks sync, blank, the CPU clock,
RDY and the bus, but it tells you nothing about the graphics path — every pixel
is legitimately black. Check that a new trace actually contains picture before
you trust a PASS from it.

## Running the comparison

```bash
python sim/run.py sim/traces/hmove.trace
python sim/run.py --quiet                       # all traces, summary only
python sim/run.py --debug --from 53668 --to 53700 \
       sim/traces/local/donkeykong-boot-to-picture.trace
```

`--debug` switches to `tb_debug.v`, which prints the core's internal state
beside the die's pins for a window of records. `tb_trace.v` also takes
`+dump=FILE`, which writes the core's luminance, colour, sync, blank, RDY, data
bus drive and colour burst for every scored record; comparing that with the
trace a scanline at a time is the fastest way to see *how* something diverges —
a constant offset, a pixel too wide, a copy missing.

### The board around the core

`tb_board.v` replays a console-wired trace into `rtl/tia_board.v` instead —
the logic between the core and the board's pins — and checks what the board
drives: the colour clock counted out of the PLL clock and CLK2 rebuilt from
Φ0, record for record against the trace; Φ0, RDY, sync, BLK and luma on the pins;
D7/D6 wherever the die drove them, with A5-A0 beneath; the chroma waveform's
phase for every hue, measured against the burst's; and the pulse widths on
both sound pins, for both settings of `AUDIO_STEREO` at once.

```bash
iverilog -g2005 -I rtl -s tb_board -o tb_board.vvp sim/tb_board.v rtl/*.v
vvp tb_board.vvp +trace=sim/traces/phi2/ball.trace
```

### Alignment

A trace starts wherever the recording started, while the core comes out of
reset at the top of a scanline. The testbench therefore replays the trace at
every one of the 456 offsets within a scanline and keeps the one with the
fewest sync errors, then reports the offset it chose. Every trace in this
repository starts with an RSYNC, which makes the choice moot; `+align=0` skips
the search.

This is a property of the harness, not a tolerance in the RTL. Sync is a pure
decode of the horizontal counter: if no offset produces a clean match, the
counter is wrong and that is a real finding. Nothing is scored for the first
2,000 records (`+warm=N`) or before the next HBLANK edge, because a trace that
starts at power-on begins inside the 6507's reset sequence; after that, every
record is checked.

## Trace format

One line per TIA half clock, all fields hexadecimal:

```
clk0 clk2 rw cs0 cs3 ab db inpt | ph0 rdy_low sync_low lum col blk_low au0 au1 dbdrv
```

The first eight are stimulus, the rest are what the die drove. `lum` and `col`
come from Sim2600's own `get3BitLuminance()` and `get4BitColor()`. `sync_low`,
`rdy_low` and `blk_low` are the drive-low control wires, so 1 means the chip is
pulling that pad to ground. `dbdrv` is
`{DB7_drvHi, DB7_drvLo, DB6_drvHi, DB6_drvLo}` — the TIA only ever drives those
two data lines.

`au0` and `au1` are the four weighted taps of each audio pad, 3.75k as the
most significant bit and 30k as the least, so they read back as the AUDV value
while the tone is high. Sim2600 names its taps the other way round from the
registers — its `AU1_*` wires follow AUDV0 — and `gen_trace.py` swaps them
back.

**`ab` and `db` are zeroed wherever the TIA is not chip-selected.** The die
ignores the bus in those records and so does the core, so the comparison loses
nothing — replaying a scrubbed copy of the Donkey Kong trace gives exactly the
same result as the raw one. What it does lose is the cartridge's program, which
otherwise rides the data bus into the trace every time the 6507 fetches from
ROM. `gen_trace.py --raw-bus` keeps everything, for local investigation.

## Looking inside the die

When a mismatch will not give way to reasoning about pins, look inside the
die. Sim2600's TIA has 2,660 wires, and every one of them can be recorded:

```bash
pip install numpy
python sim/probe_die.py --sim2600 ../Sim2600 \
       --rom sim/roms/build/players.bin --count 51072 --out players.npy
```

This runs the cartridge exactly as `gen_trace.py --skip 0` does, so record k
of the probe is record k of the committed trace, and it adds little to the
simulation's own running time. Only the pads, the register strobes and a few
buses have names; every other wire is `N<index>`, so the other half of the job
is reading the logic around a wire:

```bash
python sim/netlist.py --sim2600 ../Sim2600 node  RESP0_metal
python sim/netlist.py --sim2600 ../Sim2600 tree  N2203 --depth 4
python sim/netlist.py --sim2600 ../Sim2600 loads N1703
python sim/netlist.py --sim2600 ../Sim2600 waves --probe audio.npy \
       --trace sim/traces/audio.trace --line 60 N1703 N2591
```

The recipe behind the reset and audio findings below: follow a named strobe
to the latches it forces; find a register's bits by correlating every wire
with a model's state, since a real bit agrees on every sample; read where each
clock sits in the line with `waves`; then read the logic with `tree`. Where a
model still disagreed with the die, the die's own latches showed which tick
went wrong. With two wirings to record, one more trick earns its keep: probe
the same cartridge through both checkouts and print the same wires around the
same write side by side.

## What the traces have settled

Everything here contradicts, sharpens or simply is not in the published
documentation, and each is now a comment in the RTL next to the code that
implements it.

**Clocks and the horizontal counter**

- **The horizontal counter runs on the falling edge of the colour clock, and
  the sync latch on the rising edge**, three half clocks earlier. Towers' table
  lists both as "delayed 4 CLK", which is right to within a count but not to
  within a colour clock. HBLANK always rises on a record where `clk0` is low,
  sync always on one where it is high, and sync rise is always exactly 37 half
  clocks after HBLANK rise — 40 for five counter states, minus three.
- **Φ0 is a 50 per cent square wave**, three half colour clocks high and three
  low, so the die divides by three on both edges. **The horizontal counter
  reloads it:** it rises on exactly the half clock where HBLANK starts, every
  line, with either wiring.
- **RSYNC restarts the counter seven half clocks after the last half clock its
  strobe shares with PH0 low.** RSYNC's decode is a NOR that takes PH0 as one of
  its inputs, so of the three half clocks its strobe is high, only those with
  PH0 low count. HBLANK comes on at the restart and Φ0 reloads, which cuts both
  its halves to two half clocks with Sim2600's wiring and cuts nothing with the
  console's. Towers left RSYNC as "requires more investigation"; counting from
  the write instead, as this core first did, fits one wiring and misses the
  other by four half clocks.

**The bus**

- **The data bus drivers are enabled only while the die's CLK2 pad is high** —
  three half clocks of the six-half-clock bus cycle, Φ2 on a console — on every
  selected read, including the two read addresses with no register behind
  them, which read as zeros.
- **Every write strobe is high for the three half clocks CLK2 is low after the
  write.** The decode is latched while CLK2 is high; the strobe follows.
- **RDY is released by a pulse eight half clocks long, starting three half
  clocks before HBLANK.** WSYNC's strobe sets a latch that pulls RDY low; the
  pulse clears it in whichever of its half clocks the colour clock is low, the
  first of them one colour clock before HBLANK. The same pulse is an input to
  WSYNC's decode, so a strobe that overlaps it only sets RDY once it ends, and
  a strobe entirely inside it is lost.

**The picture**

- **The playfield and blanking reach the pads directly on the falling edge;
  objects and the colour registers go through a latch on it.** Latching the
  playfield too puts it a colour clock right of the die and lets the last pixel
  of every line leak into HBLANK.
- **Each playfield bit is read out of PF0-PF2 on H@1 and shown from the next
  H@2**, so a mid-line write appears at the next bit boundary only if it beats
  that boundary's H@1.
- **SCORE switches to the right-hand colour one colour clock before the second
  half starts, and the priority bit turns SCORE off** — with PFP set the
  playfield keeps COLUPF.
- **The colour pad carries the colour clock itself, and is released when there
  is no colour.** For hues 1-15 it toggles every half clock; for hue 0, and
  through blanking, it is left alone. The burst runs from RHS to RCB — Towers'
  "reset colour burst" — starting one half clock after the sync pulse ends,
  and it is not sent on lines VBLANK blanks.

**The pads**

- **Every video and sound pad is a pull-down transistor and nothing else**:
  SYNC, LUM0-2, COL, AUD0, AUD1, BLK and RDY. The console supplies the
  pull-ups. Φ0 is the only output driven both ways.

**Objects** — read off the netlist, with the tools under *Looking inside the
die*

- **A RESxx strobe does not reset the counter. It holds the object's
  two-phase clock in H@1 and sets a latch.** The two-phase clock is a ring of
  four half-clock stages. For as long as the strobe is high the ring is cleared
  and read as H@1; on the next H@2 the latch lets go and starts a pulse one
  count long that forces every stage of the counter to zero. The counter
  therefore clears on the first H@2 after the strobe and counts on from there.
- **How many object clocks the hold swallows depends on where the strobe
  falls.** Its three half clocks cover one MOTCK phase with Sim2600's wiring
  and two with the console's. On this core's clock grid, which runs three half
  clocks behind the die's ring, the hold is the strobe's window three half
  clocks later.
- **That is why a copy already on its way can survive a reset.** START decodes
  pass through a latch that follows them for all of H@1, so holding the ring
  in H@1 catches a START decoded just before the strobe and clocks it out on
  the new phase — if the decode is still true when the held H@1 ends, which
  with the console's wiring it more often is not.
- **In HBLANK the ring cannot move**, because MOTCK is stopped: a reset there
  waits in H@1 for the first colour clock of the visible line and clears the
  counter on the second.
- **The ball's START is its counter's clear pulse, and its width is that pulse
  plus a delayed copy.** The clear, whether from RESBL or from the wrap, lasts
  one count, and a second latch stage repeats it for the count after. One and
  two pixels are the first colour clocks of the first count, four is that
  count, eight is both. Strobe RESBL again while the copy is running and the
  die draws one unbroken run, which a width counter reloaded on every START
  cannot do. Missiles take their width the same way.
- **Double- and quad-size players start one colour clock later than
  single-size ones**, and their first stretched pixel is as wide as the rest.
  The scan counter itself counts every colour clock, behind a gate that holds
  it back after a half clock in neither phase (2×) or in anything but H@2
  (4×). The gate is the object's two-phase state caught by a pair of latches
  on MOTCK — the same latches START goes through — so it holds its value
  through HBLANK and follows a NUSIZ write one MOTCK late. A reset's hold reads
  as H@1, which opens a double-size player's gate and closes a quad-size
  one's: reset a stretched copy while it is being drawn and one of its pixels
  comes out half width with Sim2600's wiring, three with the console's.
- **RESMP's lock is decoded at scan position 1** of the player's main copy.

**HMOVE**

- **The first compare has to come before the first decrement.** Whether the
  counter steps down first depends only on where in the two-phase cycle
  `STA HMOVE` lands; when it does, an HMxx of −8 never matches, and the object
  receives sixteen pulses instead of none.
- **The motion process runs 12 half clocks behind the horizontal counter.**
  An HMOVE at the start of a line stuffs its pulses 33, 41, … 145 half clocks
  into it, and they count while HBLANK is on — through the HMOVE latch's
  extension to LRHB too, since that is when MOTCK is stopped. The comparators
  read the HMxx registers on that later grid, which is why Cosmic Ark's HMM0
  write, 139 half clocks into the line, still withholds the missile's last
  pulse.
- **The comparators look a little early, and the counter stops at zero.** The
  die catches each compare in a latch on the motion clock and acts on it half
  a count later, so a new HMxx value only counts if it was written a few half
  clocks before the compare. With the console's wiring Cosmic Ark's write
  lands at 142 half clocks, just too late: the missile's latch is never
  cleared, the motion counter sits at zero instead of wrapping round to match
  again, and the missile moves on every line until the next HMOVE — the
  starfield proper.
- **Past HBLANK a pulse merges into MOTCK, and the pads see it.** The motion
  clock never stops, and each object's clock is MOTCK OR (its latch AND the
  motion clock), so in the visible line a pulse fills in a low half of MOTCK.
  That gains no count — an HMOVE in the middle of the line moves nothing —
  but Sim2600 settles MOTCK's fall before the motion clock's rise, and in that
  instant the object's latches step: the probe shows M0's slave latch
  changing on a half clock that ends with its clock high, which only a
  momentary low can do. The object shows its next state half a colour clock
  early, on exactly the half clock the pads latch it, and its next MOTCK
  finds nothing left to do. That is how a one-pixel missile beside its player
  vanishes after a mid-line HMOVE, and how Cosmic Ark's moving missile loses
  or gains a pixel on some lines.

**Audio** — also read off the netlist, then checked tick by tick against the
die's own divider and counters, not just its pads

- **Each audio tick has two phases.** Phase A, at counts 1 and 19, compares
  the divider with AUDF, latches the result as the tick's enable and, on an
  enabled tick, latches the hold decision and the feedback bits from AUDC as
  it is at that moment. Phase B, at counts 9 and 37, shifts the counters; the
  pads change there, 112 and 116 colour clocks apart rather than an even 114.
- **AUDF is compared, not loaded.** The divider is a binary counter cleared on
  an enabled tick, so lowering AUDF below the count lets it run on to 31 and
  wrap before the channel ticks again.
- **The pulse counter has no lockup guards.** Stella keeps its 4-bit
  polynomial away from %1010 and the divide-by-6 away from %0000; the netlist
  has neither term, and the simulated die does step from %0000 to %1111 in
  AUDC C.
- **The two channels are not wired alike.** Channel 0's phase-A latches follow
  the enable latched in that same phase; channel 1 takes the enable through one
  more latch and follows the tick before, which is how Stella models both.
  The difference only shows on the first tick after the divider lets a
  channel run again with AUDC changed in the meantime — one period of one
  channel, which on a console that joins the two sound pins, as an unmodified
  2600 does, is lost in the mix.
- **AUDC 0 and B hold the output at the AUDV level** — a DC offset, not silence.

**Inputs**

- **VBLANK D7 grounds the paddle inputs**, which then read as zero.

## Known gaps

- **Merged HMOVE pulses are a race.** On the die MOTCK falls as the motion
  clock rises; Sim2600 settles the fall first and the core follows it (see
  *HMOVE*). A real chip may not glitch at all, and no trace reads collisions
  while a pulse merges.
- **Whether real chips share the audio channels' asymmetry** (see *Audio*), or
  it came in with the extraction of the netlist. Sim2600 is the only oracle,
  so the core follows it and `tia_audio.v` keeps the difference to one
  parameter; on an unmodified console it is inaudible either way.
- Nothing drives the joystick or console switches. Sim2600 holds I0-I5 high,
  so the trigger latch has never been exercised.
- One die revision. There are at least twelve NTSC TIA revisions with
  observable differences, and Sim2600's netlist is the 10444D.
- The board wrapper has been simulated, synthesised with Yosys
  (`fpga/check_synth.py`) and built with Gowin EDA, but not run on hardware.

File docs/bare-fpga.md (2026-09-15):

# Should the FPGA go straight on the board?

The board hangs a Sipeed Tang Nano 9K module off two socket strips. The alternative
is a bare FPGA soldered to the board. This note is the reasoning, so the decision
does not have to be made twice.

**Short answer:** for a board that lives inside a closed console, yes, clearly.
For hand-built prototypes, the module is the right call and you already own one.

---

## The module's pin count has shaped every compromise in this design

That is not a figure of speech. Go through what the board gives up, and every item
traces to the same 29 usable GPIO:

| Compromise | Why |
|---|---|
| Φ2 is not read by the FPGA | Its pin was traded for chroma. There was no third option |
| The four paddles are not implemented | No pins left at all |
| U5 exists | An extra gate, so the 245's `/OE` costs no FPGA pin and the two chip selects cost one |
| 8 header pins are stranded | J6/2–9 are a 1.8 V bank; unusable without a second rail |
| GND reaches the module on one pin | J6/23 is the only ground the headers expose |

A part in a TQFP-100 has **80 I/O**. The design needs about 36. The shortage
simply ends, and with it U5, the Φ2 sacrifice and the paddle limitation.

## Height is the other half, and it may be decisive

The module stack is a socket strip (8.5 mm) plus the module PCB (1.6 mm) plus
its HDMI connector (~5 mm) — roughly **20 mm above this board**, which itself
sits on pins above the console's PCB. A bare FPGA is about **1 mm**.

The vertical clearance inside a closed 2600 above a DIP-40 socket is the one
number in this project nobody has measured. If it turns out to be tight, the
bare FPGA is not an option among others — it is the only one.

## What it costs

The module is not just an FPGA. It is an FPGA **plus** regulators, configuration
storage, a USB-JTAG bridge and a known-good assembly. Dropping it means you
provide those:

- **Fine-pitch soldering.** TQFP-100 is 0.5 mm pitch. Drag-solderable by hand
  with flux and braid, but it is a different skill from 1.27 mm SOIC. QFN, which
  is where the cheapest parts live, needs hot air or reflow.
- **Configuration.** Pick a part with *internal* configuration flash or you add
  an SPI NOR chip and its plumbing.
- **Power.** Pick a part with an internal core regulator or you add a second LDO.
- **Programming.** A JTAG header and a programmer, instead of a USB-C cable.
- **No quick swap.** A dead module is replaced in seconds; a dead soldered FPGA
  is a rework job.

## The part that removes most of those costs

**`LCMXO2-1200HC-4TG100`** — Lattice MachXO2, TQFP-100.

| | |
|---|---|
| I/O | **80** (against the module's 29) |
| Logic | 1280 LUT4 — the TIA needs ~311 FF and 500–800 LUT |
| PLL | 1 — needed to synthesise the 15 chroma phases |
| Configuration | **internal flash**, instant-on, no external config chip |
| Supply | **single 2.375–3.465 V**, internal core regulator, no second LDO |
| Package | TQFP-100, 0.5 mm pitch — hand-solderable |

That combination is the point: internal flash and a single supply delete two of
the five costs above. Step up to the `-2000HC` or `-4000HC` in the same package
and footprint if you want logic headroom for a scan doubler or debug
instrumentation.

Gowin's `GW1NR-9` — the same silicon that is on the Tang Nano — also has
internal configuration flash, but it comes in QFN88 at 0.4 mm pitch, which
pushes assembly toward reflow.

## What does not change

**The level translators stay.** U1–U4 exist because no modern FPGA is 5 V
tolerant and the NMOS 6507 needs V<sub>IH</sub> = V<sub>cc</sub> − 0.2 V on Φ0,
and U6–U9 because the console pulls the TIA's video and sound pads up to 5 V.
Those are properties of the 6507 and the console, not of the module, and no
FPGA choice fixes them. Anyone hoping a bare FPGA collapses this into a
one-chip board will be disappointed — it is a board of level translators
either way, and U1 remains the part the whole design hinges on.

The analogue chroma problem does not change either. Having the `F_COL` pin is
necessary but not sufficient; the RTL still has to synthesise the subcarrier
phases through the PLL.

## Verdict

| Goal | Choice |
|---|---|
| Bring up the RTL on a bench, next to a real 6507 | **Module.** USB programming, nothing to solder, swap it when you brick it |
| One repair board, hand-assembled, case left open | **Module.** The pin compromises are liveable |
| Board that closes inside a 2600 | **Bare FPGA.** Height probably forces it |
| Anything built more than a handful of times | **Bare FPGA.** Cheaper per unit, no stacking, and the pin shortage stops dictating the design |

The sensible order is the one already underway: prove the RTL on the module,
where mistakes are cheap, then respin the board around a bare MachXO2 once the
logic is known good. The module board is the development vehicle. It was never going to be
the thing that ships inside somebody's console.

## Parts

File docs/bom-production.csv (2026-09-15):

Reference | Qty | Value | Footprint | Description | Suggested_Part | Notes
C1,C2,C3,C4,C6 | 5 | 100n | C_0805_2012Metric | Ceramic capacitor 100 nF 50 V X7R | generic 0805 X7R | Decoupling for U1-U5, in the bottom margin.
C7,C8,C9,C10 | 4 | 100n | C_0805_2012Metric | Ceramic capacitor 100 nF 50 V X7R | generic 0805 X7R | Decoupling for U6-U9, one beside each in the top margin. Designators on the back silkscreen.
C5 | 1 | 10u | C_0805_2012Metric | Ceramic capacitor 10 uF 16 V X5R | generic 0805 X5R | Bulk on the +5 V rail.
D1 | 1 | MBR0540 | D_SOD-123 | Schottky diode, 40 V, 0.5 A | MBR0540T1G | Feeds the Tang Nano's 5 V pin (J1/18) from the TIA socket. Blocks the module's USB from feeding the console back. Designator on the back silkscreen.
J1 | 1 | Tang Nano 9K - mates J6 | PinSocket_1x24_P2.54mm_Vertical | Socket strip, 1x24, 2.54 mm, vertical | generic 1x24 female header | Receives the Tang Nano 9K, row J6 - the row with 5V, GND and 3V3. Mounts on the FRONT.
J2 | 1 | TIA pins 1-20 | PinHeader_1x20_P2.54mm_Vertical | Pin strip, 1x20, 2.54 mm, vertical | turned/machined round pin, 1x20 | Goes into the TIA socket. Mounts on the BACK, pins pointing DOWN. Use ROUND MACHINED pins: square header pins damage a DIP socket.
J3 | 1 | TIA pins 21-40 | PinHeader_1x20_P2.54mm_Vertical | Pin strip, 1x20, 2.54 mm, vertical | turned/machined round pin, 1x20 | Goes into the TIA socket. Mounts on the BACK, pins pointing DOWN. Use ROUND MACHINED pins: square header pins damage a DIP socket.
J4 | 1 | Tang Nano 9K - mates J5 | PinSocket_1x24_P2.54mm_Vertical | Socket strip, 1x24, 2.54 mm, vertical | generic 1x24 female header | Receives the Tang Nano 9K, row J5 - the 22 signal pins. Mounts on the FRONT.
U1 | 1 | 74AHCT125 | SOIC-14_3.9x8.7mm_P1.27mm | Quad buffer, 3-state, TTL-compatible inputs | SN74AHCT125D | CRITICAL. Runs from +5 V. Level-shifts PHI0 and RDY: the NMOS 6507 needs VIH = Vcc-0.2 V on its clock, which 3.3 V cannot meet.
U2 | 1 | 74LVC245A | SOIC-20W_7.5x12.8mm_P1.27mm | Octal bus transceiver, 5 V tolerant inputs | SN74LVC245ADW | Vcc = 3.3 V. DIR from buffered R/W, /OE from U5.
U3,U4 | 2 | 74LVC541A | SOIC-20W_7.5x12.8mm_P1.27mm | Octal buffer, 5 V tolerant inputs | SN74LVC541ADW | Vcc = 3.3 V. Permanently enabled (G1 = G2 = GND).
U5 | 1 | 74LVC1G32 | SOT-23-5 | Single 2-input OR gate | SN74LVC1G32DBVR | /CS0 OR /CS3: /OE for U2, and the FPGA's chip select.
U6,U7,U8,U9 | 4 | 74LVC2G07 | SOT-23-6 | Dual buffer, open-drain outputs, 5 V tolerant | SN74LVC2G07DBVR | Vcc = 3.3 V. Drive SYNC, LUM0-2, COL, BLK, AUD0 and AUD1 the way the TIA's own pull-down pads do. Designators on the back silkscreen.

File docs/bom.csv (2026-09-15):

Reference | Value | QUANTITY
C1-C4,C6-C10 | 100n | 9
C5 | 10u | 1
D1 | MBR0540 | 1
J1 | Tang Nano 9K - mates J6 | 1
J2 | TIA pins 1-20 | 1
J3 | TIA pins 21-40 | 1
J4 | Tang Nano 9K - mates J5 | 1
U1 | 74AHCT125 | 1
U2 | 74LVC245A | 1
U3,U4 | 74LVC541A | 2
U5 | 74LVC1G32 | 1
U6-U9 | 74LVC2G07 | 4

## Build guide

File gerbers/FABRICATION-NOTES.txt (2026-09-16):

tia-fpga rev B - fabrication notes
==================================

FPGA replacement for the Atari 2600 TIA (C010444).
https://github.com/lrrosa/tia-fpga
Copyright 2026 Leonardo Roman da Rosa - CERN-OHL-S-2.0

BOARD
  Size              61.6 x 34.54 mm (rectangular, no cutouts, no mounting holes)
  Layers            2 (F.Cu / B.Cu)
  Thickness         1.6 mm FR4 (standard)
  Copper            1 oz / 35 um
  Surface finish    HASL or ENIG, either is fine
  Solder mask       both sides, any colour
  Silkscreen        both sides, white

CAPABILITY REQUIRED
  Min track width   0.18 mm  (7 mil)
  Min clearance     0.13 mm  (5.1 mil)
  Min drill         0.30 mm  (vias)
  Largest drill     1.00 mm  (through-hole connector pads)
  All within standard low-cost capability. No controlled impedance, no blind or
  buried vias, no castellations.

FILES (Gerber X2 + Excellon)
  tia-fpga-F_Cu.gtl           top copper
  tia-fpga-B_Cu.gbl           bottom copper
  tia-fpga-F_Mask.gts         top solder mask
  tia-fpga-B_Mask.gbs         bottom solder mask
  tia-fpga-F_Silkscreen.gto   top silkscreen
  tia-fpga-B_Silkscreen.gbo   bottom silkscreen
  tia-fpga-Edge_Cuts.gm1      board outline
  tia-fpga.drl                drill, Excellon, mm, absolute origin
  tia-fpga-drl_map.gbr        drill map (reference only, do not fabricate)
  tia-fpga-job.gbrjob         Gerber job file

ASSEMBLY NOTE (not the fab's problem, but it matters)
  J2 and J3 mount on the BACK with their pins facing DOWN - they plug into the
  TIA's DIP-40 socket. J1 and J4 are sockets on the FRONT, facing UP. Use ROUND
  MACHINED pins for J2/J3: square header pins damage a DIP socket.

  The Tang Nano 9K goes in component side UP with its USB-C end on the left,
  pin 1 of both its rows at that end. J1 takes the module's J6 row (the one
  with 5V, GND and 3V3) and J4 takes J5. The rows are 22.86 mm apart, from
  Sipeed's own dimension drawing.

  U5, U6-U9 (SOT-23-6), C7-C10 and D1 sit in the top margin of the front. Their
  designators are on the BACK silkscreen, right behind each part: there is no
  room for them beside the parts.

  The back silkscreen also carries the licence (CERN-OHL-S v2), the author and
  the project's address, between the two rows of TIA pins. CERN-OHL-S v2 asks
  for that notice to travel with the board, so please keep it.

  ORIENTATION: the back carries a half moon at the end where the TIA's pin 1
  and pin 40 sit, the way the chip's own package is keyed, plus the pin numbers
  1, 20, 21 and 40 beside the corner pads. The front repeats 1 and 40.

DRC
  Verified with KiCad 10.0.4: 0 violations, 0 unconnected pads.

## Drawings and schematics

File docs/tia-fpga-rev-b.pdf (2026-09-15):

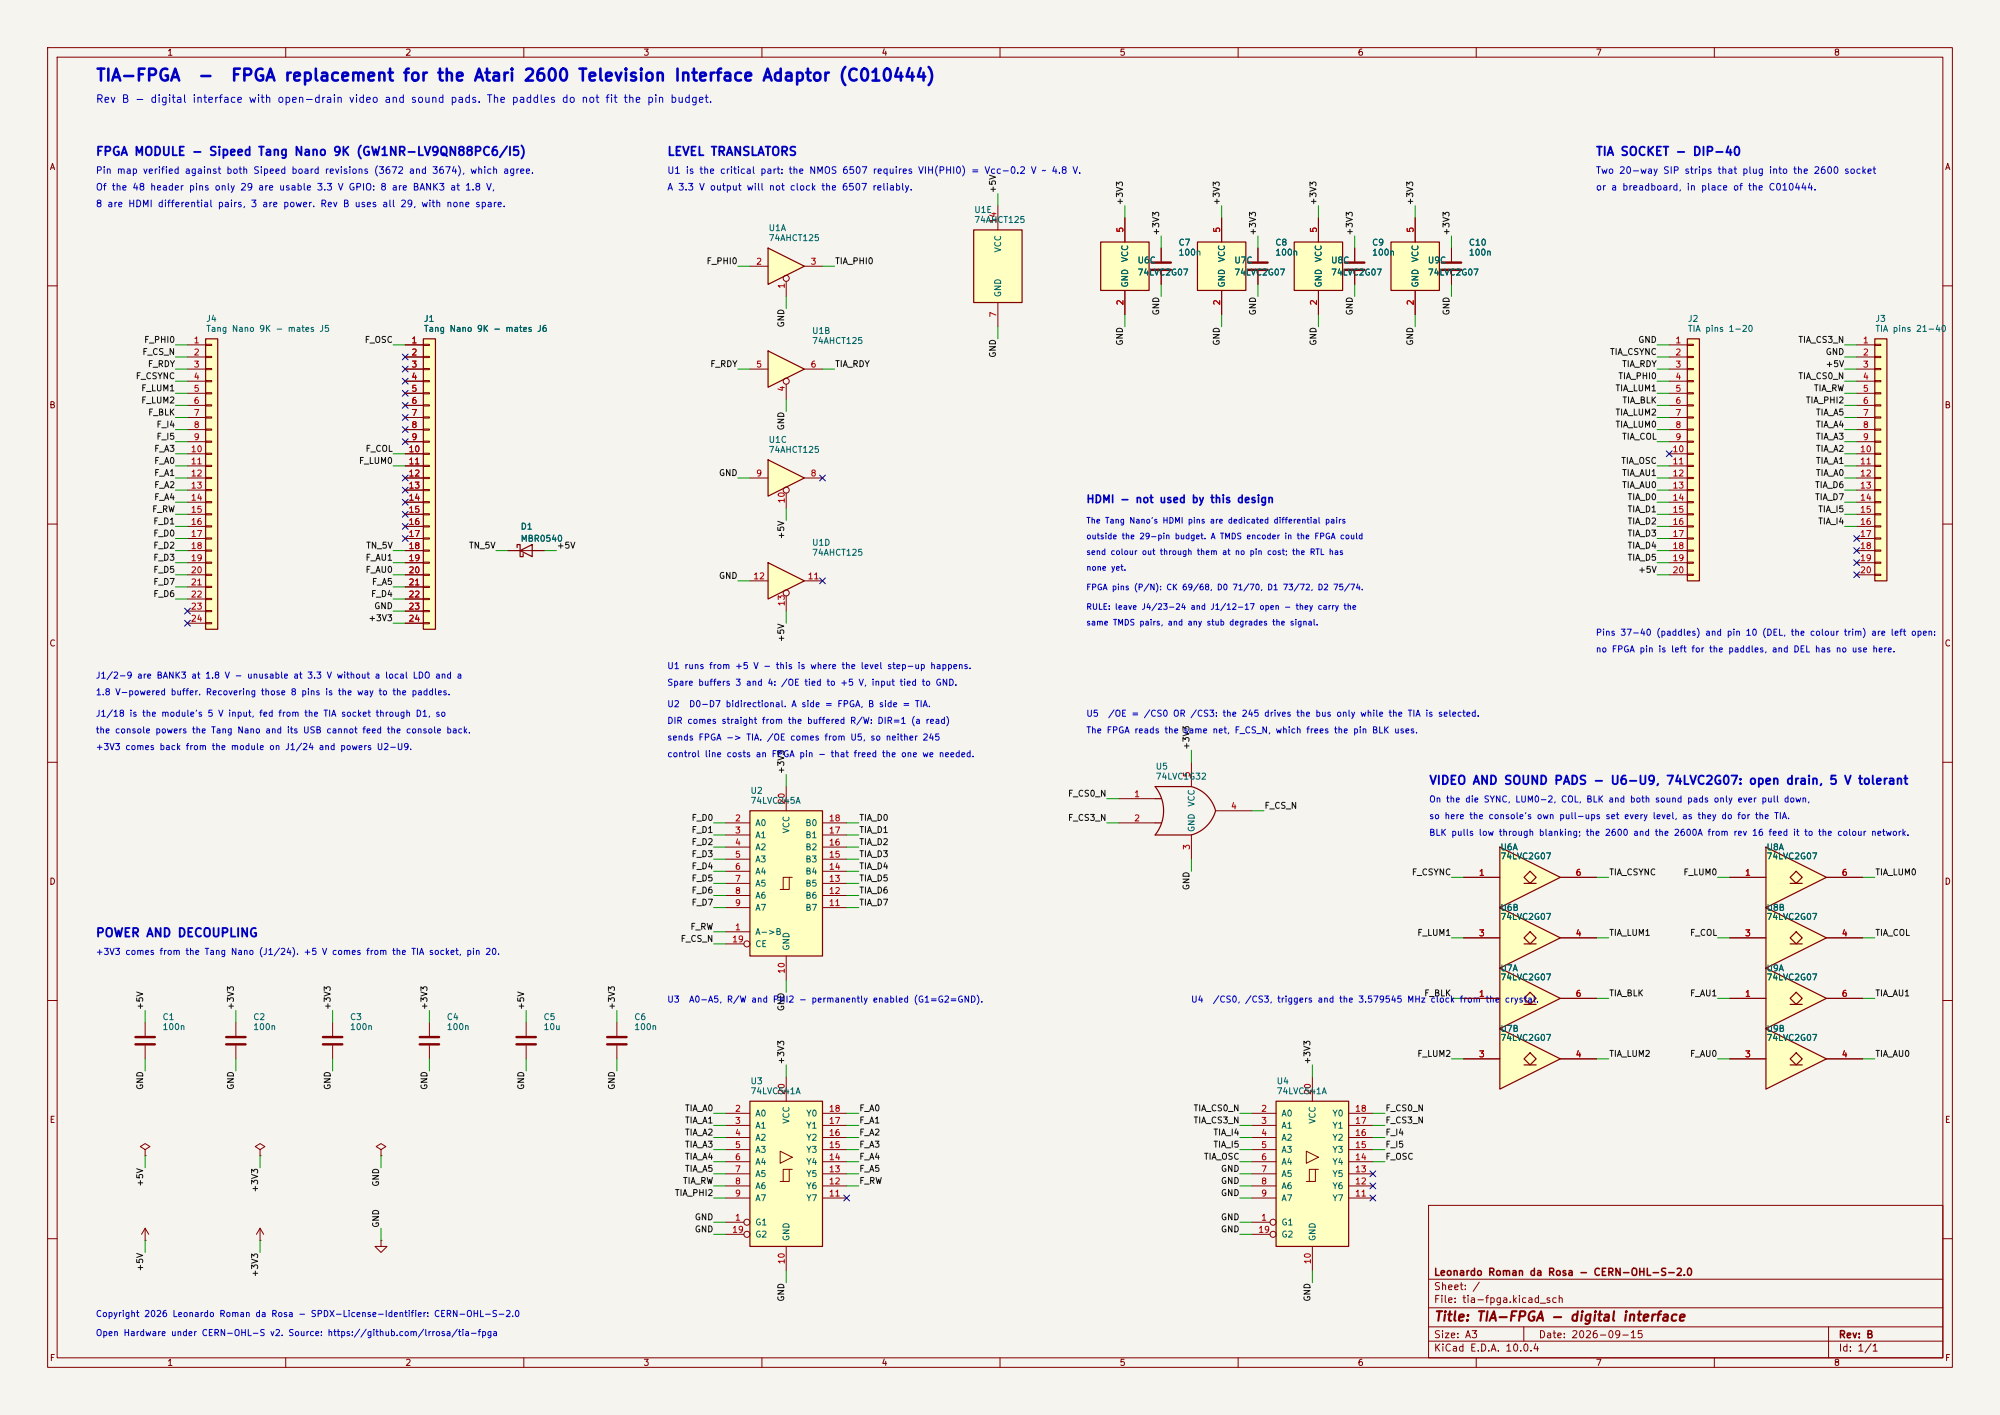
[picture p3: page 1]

TIA-FPGA - FPGA replacement for the Atari 2600 Television Interface Adaptor (C010444)

U1 is the critical part: the NMOS 6507 requires VIH(PHI0) = Vcc-0.2 V ~ 4.8 V. 8 are HDMI differential pairs, 3 are power. Rev B uses all 29, with none spare. POWER AND DECOUPLING
Of the 48 header pins only 29 are usable 3.3 V GPIO: 8 are BANK3 at 1.8 V,

Two 20-way SIP strips that plug into the 2600 socket no FPGA pin is left for the paddles, and DEL has no use here.
or a breadboard, in place of the C010444.

A 3.3 V output will not clock the 6507 reliably.

HDMI - not used by this design

The Tang Nano's HDMI pins are dedicated differential pairs none yet.

send colour out through them at no pin cost; the RTL has FPGA pins (P/N): CK 69/68, D0 71/70, D1 73/72, D2 75/74. RULE: leave J4/23-24 and J1/12-17 open - they carry the

same TMDS pairs, and any stub degrades the signal.

Spare buffers 3 and 4: /OE tied to +5 V, input tied to GND.

control line costs an FPGA pin - that freed the one we needed. sends FPGA -> TIA. /OE comes from U5, so neither 245

VIDEO AND SOUND PADS - U6-U9, 74LVC2G07: open drain, 5 V tolerant U3 A0-A5, R/W and PHI2 - permanently enabled (G1=G2=GND).

+3V3 comes from the Tang Nano (J1/24). +5 V comes from the TIA socket, pin 20. Copyright 2026 Leonardo Roman da Rosa - SPDX-License-Identifier: CERN-OHL-S-2.0 Open Hardware under CERN-OHL-S v2. Source: https://github.com/lrrosa/tia-fpga

Leonardo Roman da Rosa - CERN-OHL-S-2.0
Sheet: /
File: tia-fpga.kicad_sch
Title: TIA-FPGA - digital interface

Size: A3 | Rev: B | F Date: 2026-09-15
KiCad E.D.A. 10.0.4 | Id: 1/1

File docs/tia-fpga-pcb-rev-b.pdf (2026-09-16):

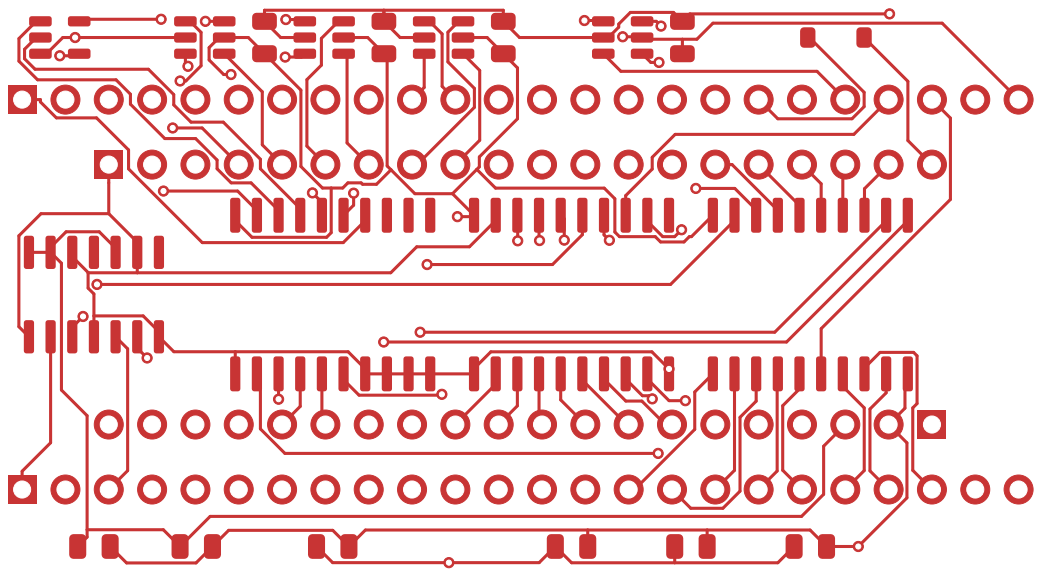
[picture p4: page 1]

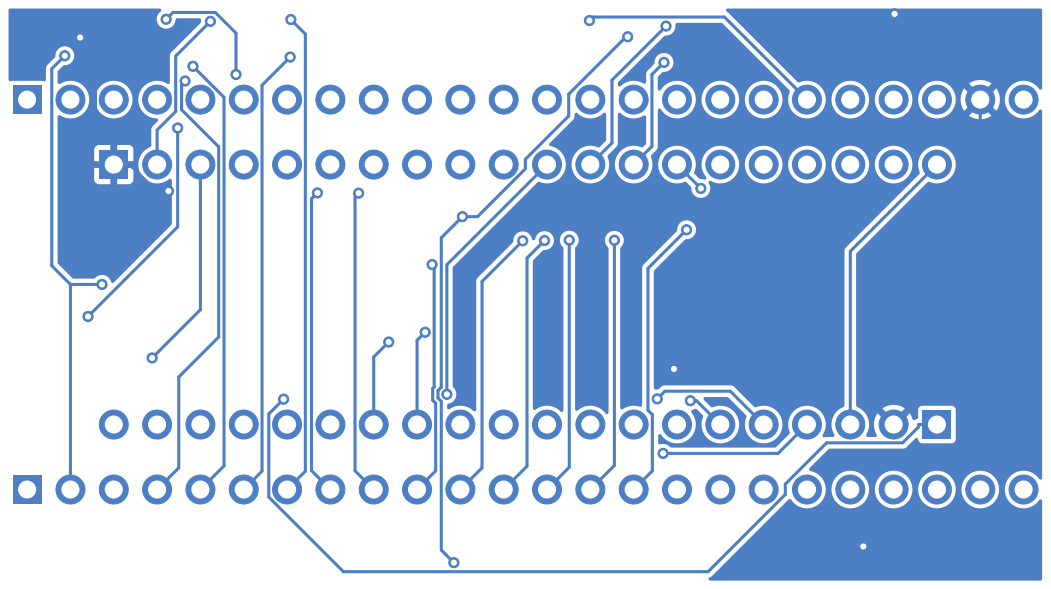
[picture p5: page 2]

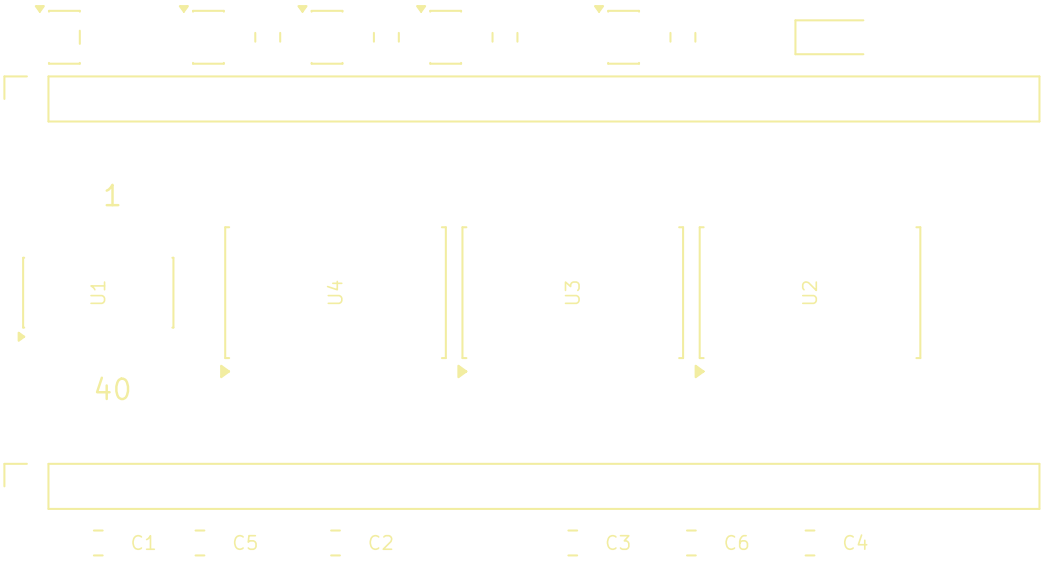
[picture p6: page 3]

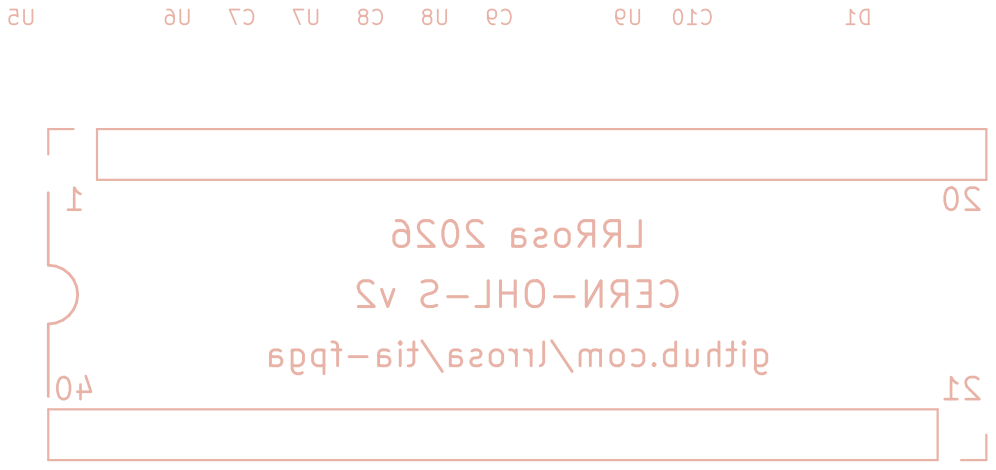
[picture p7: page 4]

21 github.com/lrrosa/tia-fpga 2026 LRRosa

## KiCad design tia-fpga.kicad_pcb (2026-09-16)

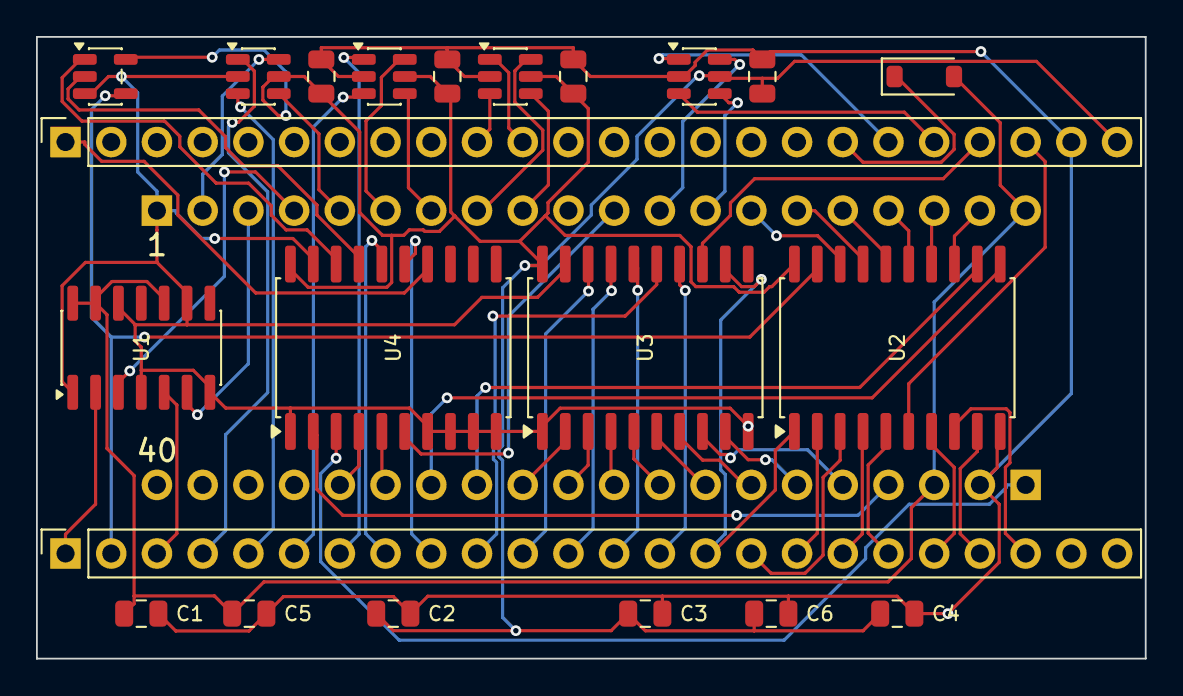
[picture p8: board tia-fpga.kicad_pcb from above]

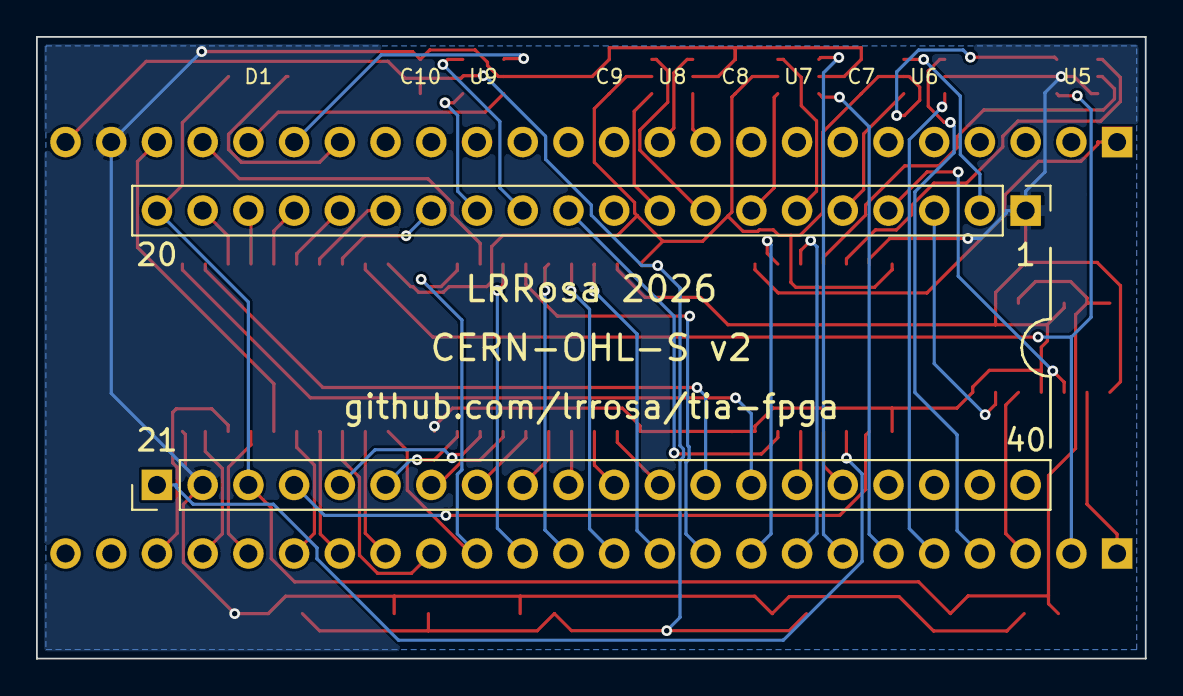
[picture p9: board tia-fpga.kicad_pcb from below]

Board: 2 copper layers, 61.6 x 34.5 mm, 24 parts (2 on the bottom side), 66 nets.

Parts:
C1, C2, C3, C4, C5, C6: C_0805_2012Metric
C7, C8, C9, C10: 100n; C_0805_2012Metric
D1: MBR0540; D_SOD-123
J1, J4: PinSocket_1x24_P2.54mm_Vertical
J2, J3: PinHeader_1x20_P2.54mm_Vertical
U1: SOIC-14_3.9x8.7mm_P1.27mm
U2, U3, U4: SOIC-20W_7.5x12.8mm_P1.27mm
U5: SOT-23-5
U6, U7, U8, U9: 74LVC2G07; SOT-23-6

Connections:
+3V3: C2.1, C3.1, C4.1, C6.1, C7.1, C8.1, C9.1, C10.1, J1.24, U2.20, U3.20, U4.20, U5.5, U6.5, U7.5, U8.5, U9.5
+5V: C1.1, C5.1, D1.2, J2.20, J3.3, U1.10, U1.13, U1.14
/F_A0: J4.11, U3.18
/F_A1: J4.12, U3.17
/F_A2: J4.13, U3.16
/F_A3: J4.10, U3.15
/F_A4: J4.14, U3.14
/F_A5: J1.21, U3.13
/F_AU0: J1.20, U9.3
/F_AU1: J1.19, U9.1
/F_BLK: J4.7, U7.1
/F_COL: J1.10, U8.3
/F_CS0_N: U4.18, U5.1
/F_CS3_N: U4.17, U5.2
/F_CSYNC: J4.4, U6.1
/F_CS_N: J4.2, U2.19, U5.4
/F_D0: J4.17, U2.2
/F_D1: J4.16, U2.3
/F_D2: J4.18, U2.4
/F_D3: J4.19, U2.5
/F_D4: J1.22, U2.6
/F_D5: J4.20, U2.7
/F_D6: J4.22, U2.8
/F_D7: J4.21, U2.9
/F_I4: J4.8, U4.16
/F_I5: J4.9, U4.15
/F_LUM0: J1.11, U8.1
/F_LUM1: J4.5, U6.3
/F_LUM2: J4.6, U7.3
/F_OSC: J1.1, U4.14
/F_PHI0: J4.1, U1.2
/F_RDY: J4.3, U1.5
/F_RW: J4.15, U2.1, U3.12
/TIA_A0: J3.12, U3.2
/TIA_A1: J3.11, U3.3
/TIA_A2: J3.10, U3.4
/TIA_A3: J3.9, U3.5
/TIA_A4: J3.8, U3.6
/TIA_A5: J3.7, U3.7
/TIA_AU0: J2.13, U9.4
/TIA_AU1: J2.12, U9.6
/TIA_BLK: J2.6, U7.6
/TIA_COL: J2.9, U8.4
/TIA_CS0_N: J3.4, U4.2
/TIA_CS3_N: J3.1, U4.3
/TIA_CSYNC: J2.2, U6.6
/TIA_D0: J2.14, U2.18
/TIA_D1: J2.15, U2.17
/TIA_D2: J2.16, U2.16
/TIA_D3: J2.17, U2.15
/TIA_D4: J2.18, U2.14
/TIA_D5: J2.19, U2.13
/TIA_D6: J3.13, U2.12
/TIA_D7: J3.14, U2.11
/TIA_I4: J3.16, U4.4
/TIA_I5: J3.15, U4.5
/TIA_LUM0: J2.8, U8.6
/TIA_LUM1: J2.5, U6.4
/TIA_LUM2: J2.7, U7.4
/TIA_OSC: J2.11, U4.6
/TIA_PHI0: J2.4, U1.3
/TIA_PHI2: J3.6, U3.9
/TIA_RDY: J2.3, U1.6
/TIA_RW: J3.5, U3.8
/TN_5V: D1.1, J1.18
GND: C1.2, C2.2, C3.2, C4.2, C5.2, C6.2, C7.2, C8.2, C9.2, C10.2, J1.23, J2.1, J3.2, U1.1, U1.4, U1.7, U1.9, U1.12, U2.10, U3.1, U3.10, U3.19, U4.1, U4.7, U4.8, U4.9, U4.10, U4.19, U5.3, U6.2, U7.2, U8.2, U9.2

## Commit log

2026-09-11 Initial commit: rev A digital interface schematic
    FPGA replacement for the Atari 2600 TIA (C010444), targeting a Sipeed
    Tang Nano 9K driving the DIP-40 socket with a real 6507 on the bus.
    Rev A covers the digital interface only:
    - U1 74AHCT125 on +5 V buffers PHI0 and RDY. This is the critical part:
    the NMOS 6507 specifies VIH(PHI0) = Vcc-0.2 V, about 4.8 V, so a 3.3 V
    FPGA output cannot clock it reliably.
    - U2 74LVC245A carries D0-D7 bidirectionally, DIR and /OE driven by the
    FPGA. LVC inputs at 3.3 V tolerate the 6507's 5 V swing.
    - U3/U4 74LVC541A bring A0-A5, R/W, PHI2, /CS0, /CS3, the triggers and
    the 3.579545 MHz crystal clock into the FPGA.
    - Video and audio run straight fro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
    [bom.csv, tia-fpga.kicad_sch]
2026-09-11 Use the verified Tang Nano 9K pin map; rework the bus control to fit
    The header pinout was read off both revisions of the official Sipeed board
    schematic (Tang_Nano_9k_3672 and Tang_nano_9K_3674), which agree exactly.
    Two things came out of that, and the second one changed the design.
    The headers are 2x24, not 2x20 as previously drawn. J1/J4 are now
    Conn_01x24 with every pin accounted for.
    Of the 48 header pins only 29 are usable 3.3 V GPIO:
    22 J5/1-22 banks 1/2 at 3.3 V
    7 J6/1,10,11,19-22 3.3 V
    8 J6/2-9 BANK3 at 1.8 V - NOT usable at 3.3 V
    8 J5/23-24, J6/12-17 HDMI differential pairs, not GPIO
    3 J6/18,23,24 power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
    [bom.csv, tia-fpga.kicad_sch]
2026-09-12 Add HDMI colour output, fix schematic text collisions, correct author name
    Colour video:
    The chroma pin (TIA pin 9) has no FPGA pin left on a Tang Nano 9K, so the
    composite output is monochrome — 8 grey levels, correct sync, everything
    else intact. Colour instead comes out of the Tang Nano's own HDMI
    connector: the 7-bit colour value never leaves the FPGA, and the HDMI
    pins are dedicated differential pairs that were never part of the 29-pin
    GPIO budget, so colour costs zero header pins.
    Documented in the schematic with the TMDS pin numbers (CK 69/68, D0
    71/70, D1 73/72, D2 75/74) and a design rule: J1/23-24 and J4/12-17 must
    stay open, because those header pins carry the same differentia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
    [tia-fpga.kicad_sch]
2026-09-12 Add rev A PCB: footprints, placement, autorouting, fabrication output
    The schematic had no footprints and there was no board at all, so this adds
    the whole chain rather than just a routing pass.
    Footprints are SOIC/0805 throughout. That is forced rather than chosen: the
    74LVC245A and 74LVC541A have no DIP version, so through-hole would have meant
    soldering adapter boards onto the PCB.
    Board is a 72 x 100 mm two-layer sandwich — Tang Nano sockets at the top, the
    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
    [tia-fpga-B_Cu.gbl, tia-fpga-B_Mask.gbs, tia-fpga-B_Silkscreen.gbo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]
2026-09-12 Ignore DRC reports too
    .gitignore covered erc*.rpt but not drc*.rpt, so a generated report got
    committed with the PCB.
2026-09-12 Rebuild the PCB compact: the 2600 has no room for a 72 x 100 mm board
    The first layout was flat — Tang Nano at one end, TIA pins at the other,
    72 x 100 mm. That is wrong for the machine it plugs into. In a real 2600
    the TIA, the 6507 and the RIOT sit millimetres apart, ringed by resistor
    networks and the cartridge slot; that board would have fouled half the
    console.
    Rebuilt as a stack. All four connector rows are now concentric on the
    2.54 mm grid — Tang Nano rows at y 5.84 and 26.16 (20.32 mm apart), TIA
    rows at 8.38 and 23.62 (15.24 mm, fixed by the package) — so the two
    pitches interleave and the board shrinks to 70 x 32 mm, roughly the Tang
    Nano's own footprint. That is 29% of the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
    [tia-fpga-B_Cu.gbl, tia-fpga-B_Mask.gbs, tia-fpga-B_Silkscreen.gbo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]
2026-09-12 Put the TIA pins on the back, add mounting holes and a ground pour, fit chroma
    Four changes, one of them a real bug.
    THE BUG: all four connectors were on the front. The Tang Nano sockets and
    the TIA pin headers were mounted on the same side, which means the board
    could never have gone into a socket — the pins pointed up alongside the
    sockets instead of down. J2/J3 now sit on B.Cu. Flipping mirrors the pad
    order, so the placement loop checks which end pin 1 landed on and spins
    the part 180 degrees about its own pad centre when it is wrong; J2 keeps
    pin 1 at the left, J3 at the right, preserving the DIP-40 wrap-around.
    This also removed the nine courtyard overlaps for free: with the header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
    [bom.csv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]
2026-09-12 Solve the pin assignment and reorder the buffers; drop the mounting holes
    The buses crossed the board because the FPGA signals were assigned to
    header positions in listing order. But which GPIO carries which signal is
    free - the Tang Nano's header-to-package map is fixed, nothing says F_D0
    has to sit on header pin 5. So it is now solved rather than listed:
    Hungarian assignment over the 29 usable positions, minimising the
    distance from each FPGA pin to the TIA pin it serves.
    Summed |x_header - x_TIA| goes from 737 mm to 127 mm, with several
    signals landing at exactly the same x as their target. The buffers are
    then ordered by the centroid of what each carries: U1, U4, U3, U2.
    Together:
    s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
    [tia-fpga-B_Cu.gbl, tia-fpga-B_Mask.gbs, tia-fpga-B_Silkscreen.gbo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]
2026-09-12 Add production BOM and fabrication archive; document the bare-FPGA question
    Fabrication output for rev A:
    - tia-fpga-rev-a-gerbers.zip, files at the archive root as PCB houses
    expect, with FABRICATION-NOTES.txt carrying the stackup and the
    capability the board actually needs (0.18 mm track, 0.13 mm clearance,
    0.30 mm smallest drill - all standard low-cost).
    - docs/bom-production.csv: grouped parts with suggested orderable numbers
    and the two assembly points that are easy to get wrong, namely that
    J2/J3 mount on the back with pins down and want round machined pins
    rather than square ones, and that R1-R9 stay unpopulated in a real 2600
    because the console already has that ladder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
    [bom-production.csv]
2026-09-12 Show the board at the top of the README
    Two 3D renders, front and back, re-rendered with a transparent background
    and cropped tight so they sit well on either GitHub theme. The pair earns
    its place by making the one thing that is easy to get wrong obvious at a
    glance: the Tang Nano sockets face up on the front, the TIA's DIP-40 pins
    face down on the back.
2026-09-12 Add a first-cut TIA core
    Twelve files of Verilog-2005: horizontal counter, playfield, players,
    missiles, ball, collisions, HMOVE, audio and the bus interface. The colour
    clock is oversampled by a faster system clock rather than used as a clock,
    so the core is one domain, one edge, no gated clocks.
    The timing details the published documentation does not pin down --
    which colour clock edge each latch uses, the shape and phase of the CPU
    clock, what RSYNC does to the counter -- were measured against Sim2600 in
    the next commit and are noted in the source where they are used.
2026-09-12 Check the core against Sim2600, half clock by half clock
    sim/ records the TIA's pins from Sim2600, the transistor-level netlist of
    the 10444D, and replays the recorded inputs into the RTL while checking the
    recorded outputs. Against Donkey Kong from power-on to its first picture,
    51,657 half clocks, the core matches sync, blanking, RDY, bus reads and both
    audio pads exactly, and differs on 13 records. Both differences are located
    and written up in sim/README.md.
    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
2026-09-13 Add test cartridges for the TIA and record their Sim2600 traces
    sim/roms has a small 6502 assembler written in Python and one function per
    cartridge: players, playfield, ball, missiles, HMOVE, collisions, vertical
    delay, and two for audio. Each clears zero page first, which strobes RSYNC and
    makes the trace independent of the phase the die powered up in, then walks
    its strobes through every sub-count phase of the object counters. make.py
    builds them and records their traces several Sim2600 runs at a time.
    These traces are the project's own work, so unlike the Donkey Kong ones they
    are committed. They compress about a hundred to one.
    gen_trace.py now swaps Sim2600's audio tap names back to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
2026-09-13 Match the die on the test cartridges
    The cartridges found what a game's title screen never exercises. The core
    now matches the die on every pin for Donkey Kong from power-on to its first
    picture and for the playfield and vertical delay cartridges, with a handful
    of located residuals elsewhere, all listed in sim/README.md.
    Measured against Sim2600 and now in the source: HMOVE compares before it
    decrements, and its stuffed pulses stop counting at RHB. A RESxx realigns the
    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
2026-09-13 Record the inside of the die, and test resets through HBLANK
    sim/probe_die.py records every wire of Sim2600's TIA -- all 2,660 of them,
    one bit each -- for every half clock from power-on, so record k lines up
    with record k of the pin trace from the same cartridge. sim/netlist.py
    reads the logic around any wire: what drives it, the NOR tree behind it,
    which storage nodes a clock loads, and where in a scanline a wire changes.
    Between them they are how the reset and audio behaviour in the next commit
    was found.
    The resets_hblank cartridge strobes RESP0 at three sizes, RESM0 and RESBL
    at every phase from the start of HBLANK to just past it. Its trace is
    committed, and so is the audio_modes trac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
2026-09-13 Reset objects and clock the sound counters as the die does
    Both were read off the netlist with the new probe tools, not fitted.
    Objects: a RESxx strobe does not zero the counter. It holds the object's
    two-phase clock in H@1 and sets a latch, and the next H@2 starts a
    one-count pulse that clears every stage. A START that was already decoded
    is caught by the held H@1 and still drawn, and in HBLANK the clear waits
    for MOTCK. START decodes are now latched as H@1 ends. On this core's clock
    grid the strobe reaches the ring one colour clock after the bus write.
    Audio: two phases per tick. Phase A, at counts 1 and 19, latches the
    enable from a compare of the binary divider with AUDF and, on enable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
2026-09-13 Match the die on every trace: object widths, scan clock, RESMP and HMOVE
    Each remaining mismatch on the test cartridges came from a place where a
    shortcut in the core and the die's circuit part company, and each was read
    off the netlist with the probe tools rather than fitted.
    Ball and missile width: the START is one count long, and a second latch
    stage repeats it for the count after. One and two pixels are the first
    colour clocks of the first count, four is that count, eight is both. A
    width counter reloaded on every START left a gap where the die draws one
    unbroken run of retriggered balls, so tia_enclock.v is gone.
    Player scan clock: the die's scan counter counts every colour clock behi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
2026-09-14 Read the size gate and HMOVE's comparators off the netlist
    With the console's wiring of PHI2 two object rules still differed from the
    die. Both are now taken from its wires:
    - The size gate of a stretched player is the object's two-phase state caught
    by a pair of latches on MOTCK, the same pair START goes through. It holds
    through HBLANK, follows NUSIZ one MOTCK late, and a reset's hold reads as
    phase A: it opens a double-size player's gate and closes a quad-size one's.
    tia_objcnt.v now exports the ring's phases instead of an after-hold flag.
    - HMOVE's comparators catch each compare in a latch on the motion clock and
    act on it half a count later, so they see a new HMxx value a lit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
2026-09-15 Build the bitstream with Gowin EDA and close timing
    fpga/build_gowin.tcl had never been run. With Gowin EDA V1.9.11.03
    Education it synthesised as written, but place and route refuses a working
    directory whose path has a space in it, and this repository lives under one.
    The script now finds the sources from its own location, so it can run from
    any directory without spaces, and says so.
    The first routed build met 57.27 MHz with 0.45 ns to spare. Every one of the
    worst paths started at the colour clock counter in tia_board.v: clk0 was a
    compare on it, and all of the core's clock enables fan out from clk0. clk0
    now comes straight from a flip-flop, set from the counter's next value so the
    wavef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
2026-09-15 Respin the board as rev B: open-drain pads and BLK
    Every TIA video and sound pad is open drain on the die, and the console's
    pull-ups and summing network are built around that. Rev B puts SYNC,
    LUM0-2, COL, BLK, AUD0 and AUD1 through four 74LVC2G07 (U6-U9, SOT-23-6,
    5 V tolerant open-drain outputs) in the top margin above J2, with 100 nF
    C7-C10 beside them. Their designators are on the back silkscreen, since
    the front has no room left.
    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
    [bom-production.csv, bom.csv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]
2026-09-15 Fix the Tang Nano interface: row spacing, row order, 5 V
    Sipeed's dimension drawing for the Tang Nano 9K settles two things this board
    had guessed. The module's header rows are 22.86 mm apart, not 20.32, and seen
    from above with the USB-C end on the left its J6 row is the upper one -- so the
    sockets were the wrong way round as well. J1 now takes J6 and J4 takes J5.
    Three sources agree on the order: the pin numbers on the module's underside,
    the QN88's own pin order in the top-side photo of Sipeed's datasheet, and
    third-party carrier boards for the module. Rev A had both errors too; nothing
    was ever fabricated from either.
    J1/18, the module's 5 V input, was left open on purpose for breadboar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
    [bom-production.csv, bom.csv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]
2026-09-16 Centre the TIA rows and trim the board to 61.6 mm
    The DIP rows sat 1.27 mm off the centre between the module's sockets, left
    over from growing the board downwards, and the ends carried more board than
    the sockets need. J2, J3 and the channel logic move down 1.27 mm, which leaves
    3.81 mm of gap on each side, and the outline loses 8.4 mm: 61.6 x 34.54 mm,
    with 0.74 mm of copper to the edge at the ends of the sockets. The board now
    reaches about 6.5 mm past the TIA's own pins instead of 10.9.
    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
    [tia-fpga-B_Cu.gbl, tia-fpga-B_Mask.gbs, tia-fpga-B_Silkscreen.gbo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]
2026-09-16 Put the licence notice on the back silkscreen
    CERN-OHL-S v2 asks for the notice to travel with the board, and until now it
    lived only in the files. The back silkscreen carries CERN-OHL-S v2, LRRosa 2026
    and github.com/lrrosa/tia-fpga, centred between the two rows of TIA pins, where
    the back had neither silk nor pads.
    DRC stays at 0 violations and 0 unconnected pads. Gerbers, drill, the PCB PDF
    and both renders follow; the fabrication notes and the README ask for the
    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
    [tia-fpga-B_Cu.gbl, tia-fpga-B_Mask.gbs, tia-fpga-B_Silkscreen.gbo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]
2026-09-16 Mark pin 1 and the keyed end on the silkscreen
    The board went out with no way to tell which end of the DIP row is pin 1. The
    back now carries a half moon at the end where the TIA's pin 1 and pin 40 sit,
    keyed the way the chip's own package is, and the numbers 1, 20, 21 and 40
    beside the corner pads; the front repeats 1 and 40. The front cannot take the
    half moon: U1's own outline is in that corner.
    DRC stays at 0 violations and 0 unconnected pads. Gerbers, drill, the PCB PDF,
    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
    [tia-fpga-B_Cu.gbl, tia-fpga-B_Mask.gbs, tia-fpga-B_Silkscreen.gbo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]
2026-09-16 Draw the keyed end the way a DIP carries it
    The pin 1 marker was a half moon floating off the end of the board, which says
    nothing on its own. It is now the package end itself: a line across the gap
    between the two rows of TIA pins, at the pin 1 / pin 40 end, with the notch cut
    into the body - what the chip and its socket carry.
    and both renders follow.
    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
    [tia-fpga-B_Cu.gbl, tia-fpga-B_Mask.gbs, tia-fpga-B_Silkscreen.gbo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]
